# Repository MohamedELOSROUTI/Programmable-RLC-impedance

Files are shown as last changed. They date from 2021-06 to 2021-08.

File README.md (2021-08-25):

# Programmable RLC impedance

The main objective of this project is to implement a programmable RLC impedance. This circuit must cover the entire inductive-resistive-capacitive range (voltage/current phase shift between -90° and +90°). The RLC load must be able to dissipate up to 5 W. Two different implementations are suggested: the analog and digital RLC impedance. A programmable RLC impedance with adjustable R, L and C can be useful to simulate the load of a generator like a motor for example. 

## Analog impedance

The first step is to design an analog impedance. A gyrator is used in order to simulate an non ideal inductor with parallel redundant resistor. The main property of the gyrator is to invert the current-voltage characteristic of an electrical component. This way, a capacitor can be used to get a non-ideal variable inductor. The inductance can be adjusted with simple potentiometers. The second step consists in removing the parallel resistors in order to simulate an ideal inductor and reach the 90° phase-shift. This objective can be achieved by connecting the Negative Impedance Converter (N.I.C) in parallel to the gyrator. After that, a more detailed study of the output current and output voltage across the op amps allows to highlight the main limitations of such circuit : see technical report .pdf

The gyrated capacitor and inductor can be connected in parallel with a potentiometer to simulate a programmable RLC impedance as shown here under : 

**<center>Figure 1 : Kicad schematics</center>**


**<center>Figure 2 : Kicad PCB footprint </center>**



As can be seen from Figure 2, three potentiometers are placed at the top of the PCB to adjust the resistive impedance (R_var), and the inductive impedance (R5_indu and R2_indu). On the other hand, R4_capa is a potentiometer used to adjust the capacitive impedance.

The size of the printed circuit track related to the generator and the opamp power supply is chosen larger to decrease as much as possible the voltage drop (and parasitic resistance).

The red track and the green track correspond respectively to the top layer bottom layer of the PCB.

The four power opamps are placed along the same row to make easy the connection of a radiator in case of high power dissipation.

More details about the choice of the components are explained in the following article (or see ): 

https://www.researchgate.net/publication/342452048_Simulation_of_a_programmable_RLC_impedance_Analog_and_digital_implementation

**<center>Figure 3 : 3D Kicad PCB top layer </center>**


**<center>Figure 4 : 3D Kicad PCB bottom layer </center>**



**<center>Figure 5 : 3D Kicad PCB oblique view </center>**



# List of components used

1. Opamps : https://www.mouser.be/ProductDetail/Texas-Instruments/OPA548T?qs=wgAEGBTxy7kyuDG8paPgyg%3D%3D
2. Potentiometers : 
    - Adjustable Gyrated capacitor : https://www.mouser.be/ProductDetail/Bourns/PTV09A-4015U-B503?qs=pxDZlBjcsChjgaXxrSM7Lg==
    - Adjustable Gyrated inductor : https://www.mouser.be/ProductDetail/Bourns/93R1A-R22-A12L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
    - Adjustable Resistor : https://www.mouser.be/ProductDetail/Bourns/96R1A-R16-A15L?qs=iuQ%252BhjgTeig0Okk2%252Boma3A==
3. Switches : https://www.mouser.be/ProductDetail/CK/FP12SPC1B1TP00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
## Digital impedance

The second step consists in designing a digital RLC impedance. By contrast to the analog impedance, the filtering process is done digitally using a microcontroller. A software feedback control approach is employed to adjust the current amplitude and the power factor regarding the input voltage.

The objective is to maintain the impedance value constant regardless of the variation of the source voltage amplitude. Many paramaters such as the sampling frequency and the resolution of the ADC/DAC may affect the quality of the output current. The voltage can be converted to current using the Howland current source. Several simulations have been performed to visualise the performance of the digital RLC filter. See technical report .pdf.

However, another circuit made of only one opamp with negative feedback called transconductance amplifier can be used to convert the input voltage into current and inject it in the generator. It acts like a current source. The transconductance ratio is fixed by the value of the resistor R1. The Current I = Vin/R. The transconductance amplifier will be used here thanks to its simplicity (only makes use of one resistor to fix the output current). For more details, get a look at : 
 https://www.allaboutcircuits.com/textbook/semiconductors/chpt-8/voltage-to-current-signal-conversion/

**<center>Figure 1 : Transconductance amplifier simplified</center>**


Choosing R = 1 Ohm insures that Vin is a "perfect" image of the output current delivered by the generator. Let's assume that we want to simulate a 1 mF capacitor (C = 1 mF). The amplitude of the output current I should be equal to : I = Vgenerator.w.C (w=2*pi*f). Thus, the microcontroller should be able to measure at each time step the sample Vgenerator (through a ADC) and cpmpute Vin = I to simulate a constant 1 mF capacitor. A digital RLC filter must be implemented in the microcontroller. Thus a DAC is necessary to convert the digital voltage to analog voltage through the positive input of the transconductance unity gain amplifier.

More details about the implementation of the digital RLC filter can be found in technical report.pdf. The choice of the sampling frequency is crucial if one desires to maintain a phase-shift of +/- 90 degrees between input voltage and output current for ideal components (inductor/capacitor). The Z-transform allows to highlight the behaviour of the phase and magnitude depending on the sampling frequency.

Warning : One of the pins of the generator mustn't be connected to GND. Otherwise, the output if the transconductance opamp can be shorted. However, the howland current source allows to deal with grounded generators.

A special care has to be taken regarding the input voltage. A unity gain instrumentation amplifier with its high input impedance is used in order to "capture" Vgenerator at the output. The INA103 is used for this purpose. Before, connecting the output of the INA103 (Vgenerator) to input pin of the 12 bits ADC, we have to make sure that it is between 0 and 5 V. To reach the objective, a voltage divider made up with 2 equal resistors are used (5,11k Ohms). It is supplied between Vgenerator and V++ (positive supply voltage of the opamp). This will add (Vgenerator + V++)/2 to Vgenerator and make sure that the input is positive. Another voltage divider (1/4) allows to rescale Vgenerator between 0 and 5 V and feed it into the ADC. 

**<center>Figure 2 : Digital RLC impedance global overview</center>**

Important note regarding the 1 Ohm resistor that fixes the transconductance ratio : since the OPA548 output is internally buffered (can reach 5A peak), the resistor shall be able to dissipate up to 25 W. Thus the choice of the resistor is important here. Furthermore, the tolerance value shall also be low in order to keep the ratio as close as possible to 1. 

The LTO100 (F1R000FTE3) thick film power resistor can be a good candidate with its 1% tolerance.



**<center>Figure 3 : Kicad Schematics </center>**
Here's the Kicad schematics with the components used for building the digital programmable RLC impedance:



**<center>Figure 4 : Kicad PCB footprint</center>**

Here is the PCB footprint of the digital RLC impedance. The red/green circuit track corresponds respectively to the top/bottom side of the PCB. A special care has been taken to deal with high current (5 A). Thicker circuit tracks have been chosen to supply the op amps. Since the 1 Ohm resistor can afford 5 Amps, it's also important to make sure that the copper circuit track doesn't add parasitic resistance (and thus dissipation of power).

2x4 pins headers have been added to connect both the ADC and the DAC to the microcontroller. The serial communication protocole used is the I2C using SDA/SCL signals. 



**<center>Figure 5 : 3D Kicad PCB top layer </center>**
Only footprints            |  With components
:-------------------------:|:-------------------------:
|

**<center>Figure 6 : 3D Kicad PCB bottom layer </center>**
Only footprints             |  With components
:-------------------------:|:-------------------------:
 |

**<center>Figure 7 : 3D Kicad PCB oblique view </center>**



# List of components used

1. Opamp OPA 548: https://www.mouser.be/ProductDetail/Texas-Instruments/OPA548T?qs=wgAEGBTxy7kyuDG8paPgyg%3D%3D
3. Data converters : 
    - DAC : https://www.ti.com/product/DAC60502#design-development##cad-cae-symbols
    - ADC : https://www.ti.com/lit/ds/symlink/adc121c021.pdf?ts=1626049868732
3. Power resistoir : https://www.mouser.be/ProductDetail/Vishay-Sfernice/LTO100F1R000FTE3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
4. Voltage regulator : https://www.mouser.be/ProductDetail/Texas-Instruments/TPS7B8450QDCYRQ1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
5. Instrumentation op amp INA103 : https://www.ti.com/product/INA103#design-development

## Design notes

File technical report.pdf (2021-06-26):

https://lib.uliege.be | https://matheo.uliege.be

## Master's Thesis : Simulation of a programmable RLC impedance (analog and digital implementation)

### Auteur : El Osrouti, Mohamed Promoteur(s) : Redouté, Jean-Michel Faculté : Faculté des Sciences appliquées

Diplôme : Master : ingénieur civil électricien, à finalité spécialisée en "signal processing and

### intelligent robotics" Année académique : 2019-2020 URI/URL : http://hdl.handle.net/2268.2/8975

Avertissement à l'attention des usagers :

Tous les documents placés en accès ouvert sur le site le site MatheO sont protégés par le droit d'auteur. Conformément aux principes énoncés par la "Budapest Open Access Initiative"(BOAI, 2002), l'utilisateur du site peut lire, télécharger, copier, transmettre, imprimer, chercher ou faire un lien vers le texte intégral de ces documents, les disséquer pour les indexer, s'en servir de données pour un logiciel, ou s'en servir à toute autre fin légale (ou prévue par la réglementation relative au droit d'auteur). Toute utilisation du document à des fins commerciales est strictement interdite.

Par ailleurs, l'utilisateur s'engage à respecter les droits moraux de l'auteur, principalement le droit à l'intégrité de l'oeuvre et le droit de paternité et ce dans toute utilisation que l'utilisateur entreprend. Ainsi, à titre d'exemple, lorsqu'il reproduira un document par extrait ou dans son intégralité, l'utilisateur citera de manière complète les sources telles que mentionnées ci-dessus. Toute utilisation non explicitement autorisée ci-avant (telle que par exemple, la modification du document ou son résumé) nécessite l'autorisation préalable et expresse des auteurs ou de leurs ayants droit.

# Simulation of a programmable RLC

# impedance

## Analog and digital implementation

### Author : El Osrouti Mohamed

### Supervisor : Redouté Jean-Michel

### Insternship supervisor : Martin Nicolas

### Master Thesis in electrical engineering

### Signal processing and intelligent robotics

## Faculty of applied science

Graduation work carried out as a part of the Master of applied science in electrical

engineering and signal processing in order to get the grade : "Civil engineer in electrical

engineering". This thesis was suggested by the Centre spatial de Liège (CSL).

i

# Acknowledgements

I would like to express my special thanks to Prof. J.-M. Redouté and Mr N. Martin for

giving me the opportunity to work on this thesis and for all their advices. I would also

want to express my gratitude to all the staff of the space center of Liège (CSL) for all

the knowledge and experience they brought me. Thanks again to everyone who, directly

or indirectly, contributed to this master thesis. My thoughts also go to my beloved sisters,

and friends who always support me during all the progress of this work. I would especially

like to express my gratitude filled with love to my mother for her support during the

years, and to my late father who mostly contributed to my success. I love you dad.

Je tiens à remercier tout particulièrement le Prof. J.-M. Redouté et Mr Martin pour

m’avoir donné l’opportunité de travailler sur cette thèse et pour tous leurs conseils. Je

voudrais également exprimer ma gratitude à tout le personnel du centre spatial de Liège

(CSL) pour toutes les connaissances et l’expérience qu’ils m’ont apportées. Merci encore

à tous ceux qui, directement ou indirectement, ont contribué à cette thèse de maîtrise

finale. Mes pensées vont également à mes soeurs et mes amis qui me soutiennent

toujours tout au long de l’avancement de ce travail. Je voudrais surtout exprimer ma

gratitude pleine d’amour à ma mère pour son soutien au fil des années, et à mon défunt

père qui a surtout contribué à ma réussite. Je t’aime papa.

ii

# Abstract

Different kinds of electronic load simulators for testing of power supply have been

developed and commercialised. A programmable RLC impedance with adjustable R,

L and C can be useful to simulate the load of a generator like a motor for example.

Some companies may be interested in testing their voltage/current generators under

some conditions and study their behaviours. Both inductive and capacitive loads can be

simulated by adjusting the phase difference between the voltage and current waveforms.

However, there exist many drawbacks, for example, it can provide only 4 modes including

constant resistance (pure resistive load), constant power, constant current and constant

voltage to simulate simple dc load. But more often, they cannot simulate a RL or RC

load with a good dynamic response. The main objective of this master thesis is to design,

manufacture and test a programmable RLC impedance. This circuit must cover the

entire inductive-resistive-capacitive range (voltage/current phase shift between−90° and

90°). The RLC load must be able to dissipate up to 5 W. Two different implementations

are suggested : the analog and digital RLC impedance with their pros and cons.

The first step is to design an analog impedance. A gyrator is used in order to simulate

an non ideal inductor with parallel redundant resistor. The main property of the gyrator

is to invert the current-voltage characteristic of an electrical component. This way, a

capacitor can be used to get a non ideal variable inductor. The inductance can be

adjusted with simple potentiometers. The second step consists in removing the parallel

resistors in order to simulate an ideal inductor and reach the 90° phase-shift. This

objective can be achieved by connecting the Negative Impedance Converter (N.I.C) in

parallel to the gyrator. After that, a more detailed study of the output current and

output voltage across the op amps allows to highlight the main limitations of such

circuits. The voltage and current saturation of the op amps limit the available range

of inductance/capacitance values. Several simulations with a real precision op amp

(AD744) are performed. Finally, those circuits have been implemented on a breadboard

in the CSL laboratory¹ with commercial op amps such as the famous LM324. The

1For more information about the CSL, see Appendix C.

iii

results in terms of output current are compared with the simulations.

The second step consists in designing a digital RLC impedance. By contrast to the

analog impedance, the filtering process is done digitally using the microcontroller

ATMEGA2560. A software feedback control approach is employed to adjust the current

amplitude and the power factor. The objective is to maintain the impedance value

constant regardless of the variation of the source voltage amplitude. Many paramaters

such as the sampling frequency and the resolution of the ADC/DAC may affect the

quality of the output current. The voltage is converted to current using a Howland

current source. Several simulations have been performed to visualise the performance of

the digital RLC filter.

Finally, the analog and digital programmable RLC impedances are compared in terms

of their maximum input voltage, inductance/capacitance range, frequency, ... It will

be shown that the digital implementation offers more flexibility to the range of the

inductance/capacitance values than the analog impedance.

Unversity of Liège

Liège, June 2020

iv | Contents

# Contents

1 Introduction | 1
2 Analog Implementation | 6
2.5 Practical implementation of the analog RLC impedance in the CSL lab . | 54

Contents | v
3 Digital implementation | 68
4 Discussion | 85
5 Conclusion | 90
6 Appendix | 91
References | 96

vi | List of Figures

# List of Figures

2.1 Circuit that represents a non-ideal equivalent capacitor which can be

2.4 Non ideal capacitor circuit from which a cut is performed at the input. . 11 2.5 Circuit that simulates an "ideal" capacitor using a N.I.C connected in parallel 12 2.6 Output current (Is2

) of the second op amp with respect to frequency (f)

2.7 Output voltage (Vs2

) of the second op amp with respect to frequency (f)

2.9 Circuit that simulates an ideal inductor by connecting in parallel a N.I.C 22 2.10 Output current (Is2

) of the second op amp with respect to frequency (f)

2.11 Output voltage (Vs2

) of the second op amp with respect to frequency (f)

2.13 Spice simulation : current Ie and voltage Ve for a 20 nF equivalent capacitor

2.15 Behaviour of the current Ie when a real 20 nF capacitor is connected to an

2.17 Spice simulation : current Ie and voltage Ve for a 4 uF equivalent capacitor

2.18 Real 4 uF capacitor connected in parallel with an ideal AC source Ve. . . 33 2.19 Behaviour of the current Ie when a real 4 uF capacitor is connected to an

2.21 Spice simulation : current and voltage Ie and Ve for a 25 mH equivalent

2.22 Real 25 mH inductor connected in parallel with an ideal AC source Ve. . 35 2.23 Behaviour of the current Ie when a real 25 mH inductor is connected to

2.25 Spice simulation : current Ie and voltage Ve for a 250 mH equivalent

2.26 Real 250 mH inductor connected in parallel with an ideal AC source Ve. . 37 2.27 Behaviour of the current Ie when a real 250 mH inductor is connected to

2.29 Spice simulation : current Ie and voltage Ve for a 20 nF equivalent capacitor
Ce. The input voltage is a sinus of amplitude 5V and of frequency 1000 Hz. 40

List of Figures | vii

2.31 Spice simulation : current Ie and voltage Ve for a real 20 nF capacitor Ce.
The input voltage is a sinus of amplitude 5V and of frequency 1000 Hz. . | 41
2.32 Circuit that simulates a 2 nF equivalent capacitor using AD744 op amps. | 41
2.33 Spice simulation : current Ie and voltage Ve for a 2 nF equivalent capacitor
Ce. The input voltage is a sinus of frequency 1000 Hz. The op amp is the

2.35 Spice simulation : current Ie and voltage Ve for a real 2 nF capacitor Ce.
The input voltage is a sinus of amplitude 5V and of frequency 1000 Hz. . 43

2.37 Spice simulation : current Ie and voltage Ve for a real 1 Henry inductor Le.
The input voltage is a sinus of amplitude 5V and of frequency 1000 Hz. . 45

2.39 Spice simulation : current Ie and voltage Ve for an ideal 1 Henry capacitor
Le. The input voltage is a sinus of amplitude 5V and of frequency 1000 Hz. 46

2.41 Spice simulation : current Ie and voltage Ve for an equivalent 100 Henry inductor Le. The input voltage is a sinus of amplitude 5V and of frequency

2.43 Spice simulation : current Ie and voltage Ve for an ideal 100 Henry capacitor Le. The input voltage is a sinus of amplitude 5V and of frequency

2.44 RLC impedance simulated using the ad744 op amps. The amplitude of the sinus input voltage Ve is set to 5V and the corresponding frequency is

2.45 Spice simulation : current Ie and voltage Ve for Le = 1 H, Ce = 2 nF and R = 50 kΩ. The input voltage is a sinus of amplitude 5V and of frequency

2.47 Spice simulation : current Ie and voltage Ve for L = 2 H, C = 2 nF and R = 1 kΩ. The input voltage is a sinus of amplitude 5V and of frequency

2.48 Ideal switching RL-RC impedance. The user is free to choose the phase between [-90°, 0°] by activating the RC load or between [0°, 90°] by

2.50 Capacitor simulated : 2 nF. These plots compare the characteristics of the hardware implementation (on the left-hand side) and the spice simulation (on the right-hand-side) in terms of the output voltage (Vs1

) of the first
op amp, the output voltage (Vs2
) of the second op amp and the output
2.51 FFT of the output current (Ie) from the hardware implementation. . . . | 57
2.52 Capacitor simulated : 20 nF at 1000 Hz. | These plots compare the
characteristics of the hardware implementation (on the left hand side) and
the spice simulation (on the right-hand side) in terms of the output voltage
(Vs1

) of the first op amp, the output voltage (Vs2
) of the second op amp

viii | List of Figures
2.53 FFT of the output current (Ie) from the hardware implementation. . . . | 59
2.54 Frequency response of the equivalent capacitor circuit (with LM324 op amps) for different capacitor values : 2 nF (left figure), 20 nF ( right
figure). Small signal analysis with amplitude 1 Volt | | 59
2.55 Circuit that simulates an ideal inductor using the LM324 op amp | | 60
2.56 Inductor simulated : 100 mH. These plots compare the characteristics
of the hardware implementation (on the left hand side) and the spice simulation (on the right-hand side) in terms of the output voltage (Vs1

)
of the first op amp, the output voltage (Vs2
) of the second op amp and the
output current of the source generator (Ie) | | 62
2.57 FFT of the output current (Ie) from the hardware implementation. . . . | 63
2.58 Inductor simulated : 1 H. These plots compare the characteristics of the hardware implementation (on the left hand side) and the spice simulation
(on the right-hand side) in terms of the output voltage (Vs1

) of the first
op amp, the output voltage (Vs2
) of the second op amp and the output
current of the source generator (Ie) | | 64
2.59 FFT of the output current (Ie) from the hardware implementation. . . . | 65
2.60 Frequency response of the gyrator circuit (with LM324 op amps) for different inductor values : 10 mH (top left figure), 100 mH (top right
figure) and 1 H (last figure). Small signal analysis with amplitude 1 Volt. | 66
3.1 Schematic of the digital implementation of the RLC impedance | | 68
3.2 Simplified representation of the digital implementation. | The current
injected to the generator is controlled by the microcontroller. | It’s
proportional to the current that would flow into an inductor or capacitor. | 70
3.3 Simulated capacitor : 1 mF. Left plot : continuous output current. Right plot : discrete output current generated by the microcontroller at sampling
frequency 5000 Hz. The input voltage is a 100 Hz sine wave | 72
3.4 Simulated inductor : 1 mH. Left plot : continuous output current. Right plot : discrete output current generated by the microcontroller at sampling
frequency 5000 Hz. The input voltage is a 100 Hz sine wave | | 72
3.5 Bode plot of a continuous ideal capacitor (1 mF) | | 74
3.6 Bode plot of a continuous ideal inductor (1 mH) | | 75
3.7 Bode plot of the digital ideal capacitor (1 mF) transfer function for different sampling frequency : F s1, F s2,F s3, F s4 and F s5 respectively equal to 1,
2, 3, 4 and 5 kHz | 77
3.8 Bode plot of the digital ideal inductor (1mH) transfer function for different sampling frequency : F s1, F s2,F s3, F s4 and F s5 respectively equal to 1,
2, 3, 4 and 5 kHz. | | | 78
3.9 Full-wave precision rectifier | | 80
3.10 Comparator that outputs logical "1" if the input voltage is below the
reference : 0 V | | 80
3.11 Voltage follower | | 81
3.12 Howland current source. Vdac is the controlled voltage at the output of
the DAC. It has to be converted into current. Vin_micro is the voltage of
the generator which goes into the input pin of the microcontroller (before
the voltage rectifier) | 82
3.13 Final embedded digital implementation. See Appendix A for a landscape
format of the digital implementation. | | | 85

List of Figures | ix
6.1 Final digital implementation of the programmable RLC impedance. . . . | 91
6.2 Final analog implementation of the programmable RLC impedance. . . . | 92

x | List of Tables

# List of Tables

4.2 Comparisons of available inductance/capacitance ranges between

1

# 1 Introduction

## 1.1 Motivation and State of art

Simulated loads are crucial if an industry desires to test its power equipment under some

specific conditions (fixed inductance range, ...). Those features should provide real world

simulation capabilities and prevent overstressing the instrument. Furthermore, a DC/AC

electronic impedance plays an essential role in current and future power source testing,

especially in the field of renewable energies. Different kinds of loads maybe relevant

according to the technical specifications :

1. constant power load : the load adjusts its internal impedance to dissipate constant

power.

2. constant impedance : two kinds : a resistive impedance and a z impedance which

covers the entire complex plane.

A well-known programmable active impedance has been studied and developed by

Guan-Chyun Hsieh and Jung-Chien Li[1] in 1993. They suggested an AC active load

simulator circuit which can simulate a desired load impedance with a power factor

from zero to unity. They employed a software feedback control approach to adjust the

current amplitude and the power factor for the purpose of maintaining the impedance

value constant regardless of the variation of the source voltage amplitude. The Ph.D

of Wei Feng[2] proposes a proper schematic of the inductive/capacitive electronic loads

based on the H-bridge dc-dc converter. Another relevant research paper [3] presents

a programmable power electronic, constant power load (CPL) using a dc/dc step-up

(boost) converter.

Many programmable kinds of impedances have been developed. The LED Load Simulator

Model 63110A sold by Chroma[4] can simulate the behaviours of LED’s. It contains a

programmable interface to model the LED’s dynamic resistance. Unfortunately, it’s not

able to simulate an inductive or capacitive load. Recently, Measurements International

developed a programmable impedance simulator which covers the entire complex plane[5].

2 | 1.2 Analog Impedance

This feature has been designed to address and fill the need requirement for a better way

to calibrate LCR meters. The Z100 model covers the full calibration of LCR meters

over simulated impedance from 100 Hz to 20 kHz. The magnitude of the synthesised

impedances ranges from 1 Ω to 10 MΩ with an arbitrary phase angle. In the Z1000,

the current and the voltage measured by the LCR meter to calculate the impedance are

independently generated by two external voltage sources. Adjusting the amplitudes and

the relative phase of the voltage sources, the synthesized impedance can cover the entire

complex plane. The developers do not reveal more information about the hardware of

their product. They only mention that their device is based on a feedback loop in order

to control the output current and the phase. One thing is certain, the device is only able

to dissipate miliwatts of power and can’t be used to simulate the load of a generator.

## 1.2 Analog Impedance

The first objective is to simulate an analog RLC impedance circuit where the value

of the resistor, the capacitor and the inductor are freely chosen by a random user.

There are useful circuits for designing a filter or simulating a motor, for example. The

user wouldn’t have to change physically the inductor component in order to change

its value. The same would apply for the capacitor even though digitally controlled

variable capacitors are available. For example the NCD2400M[6] component is a digital

programmable capacitor which acts like a capacitance decade box. Many capacitors are

connected in parallel and some switches are open or closed in order to activate or not

the capacitors. Such components won’t be used for the rest of the project due to their

large step size (coupled to a small available capacitance range).

The phase between the voltage and current should be between [-90°, 90°]. -90° corresponds

to a pure capacitor and 90° corresponds to pure inductor. The presence of the resistor

changes the phase between -90° and 90°. Adjusting the value of the resistor is easy, a

simple analog potentiometer can be used. Furthermore, some digital potentiometers are

available and can be controlled via a microcontroller. For the capacitor and the inductor,

it’s a little bit more complicated. Useful circuits, named gyrators[7], made of operational

amplifiers can be used in order to simulate the value of the capacitor or inductor by

1.2 Analog Impedance | 3

adjusting potentiometers[8].

As a first approximation, the op amps are assumed to be ideal:

1. Infinite open-loop gain which doesn’t depend on frequency.
2. Infinite input impedance which implies zero input current.
3. Zero input offset voltage.
4. Infinite output voltage range.
5. No output current limitation (this condition limits the range of inductor and

capacitor values).

6. Zero output impedance (sometimes not specified in datasheets).
7. Infinite bandwidth with zero-phase shift and infinite slew rate.
8. Zero noise.
9. Infinite common-mode rejection ratio (CMRR).

The circuit that has to be simulated is shown in Fig1.1. It represents a resistor, a capacitor

and an inductor connected in parallel whose values can variate. An equivalent RLC series

circuit can be derived from this.

4 | 1.3 Digital Impedance

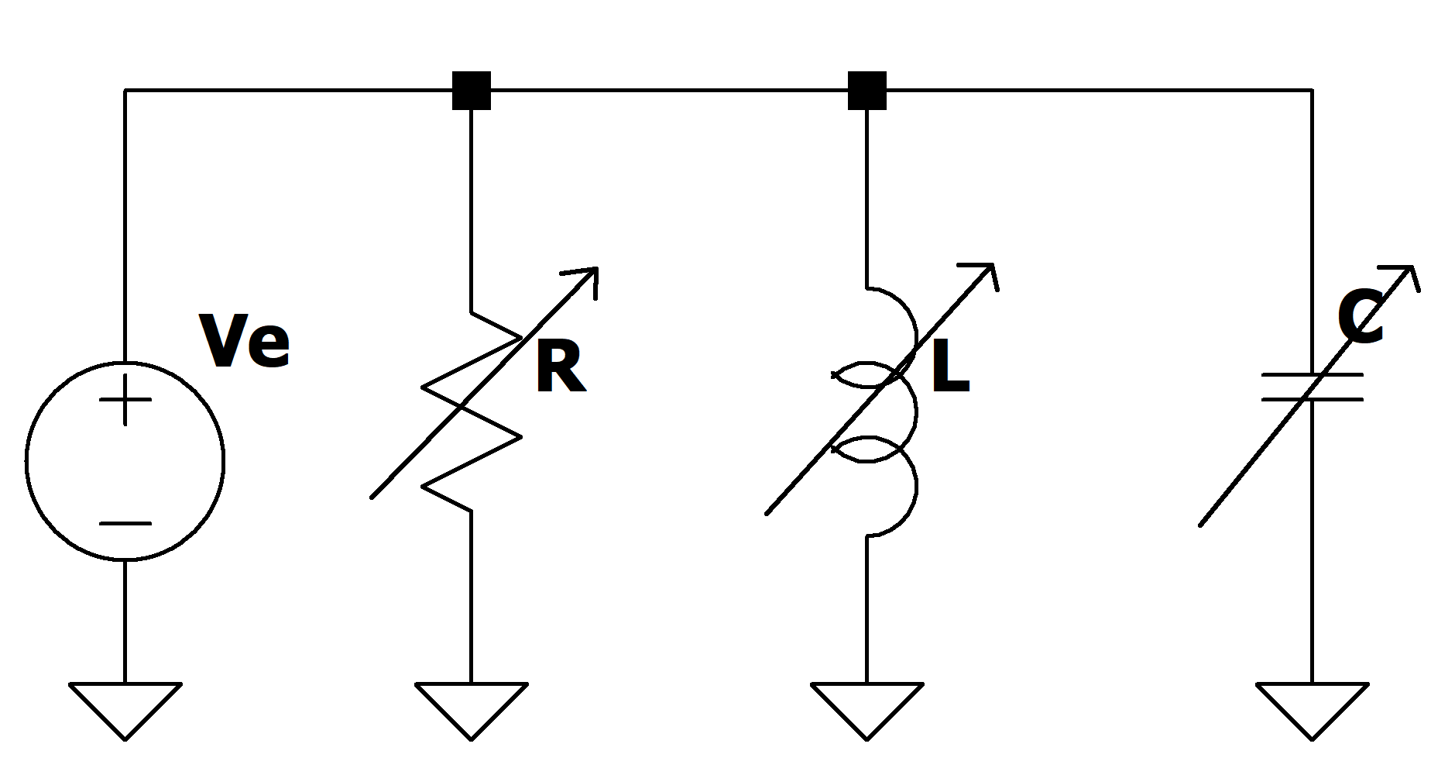
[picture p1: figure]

Figure 1.1: RLC parallel impedance

## 1.3 Digital Impedance

By contrast to the analog impedance, the filtering process is performed digitally. The

value of the capacitor and the inductor are adjusted on software. The microcontroller is

in charge of computing the output current of the generator. Many parameters may affect

the quality of the digital impedance such as

- the sampling frequency (limited by the internal clock of the microcontroller),
- the resolution of the ADC (determined by the number of bits),
- the resolution of the DAC,
- the maximum input voltage of the µC,

The digital implementation can be modelled using a voltage-controlled current source

where the microcontroller is in charge of:

1. Measuring the input voltage thanks to its ADC
2. Computing the output current that should be injected to the generator depending

on R, L, C and type of connectivity (parallel or series).

3. Outputting the voltage (image of the output current) to the DAC. This one will be

thus converted to current thanks to voltage controlled current source.

1.3 Digital Impedance | 5

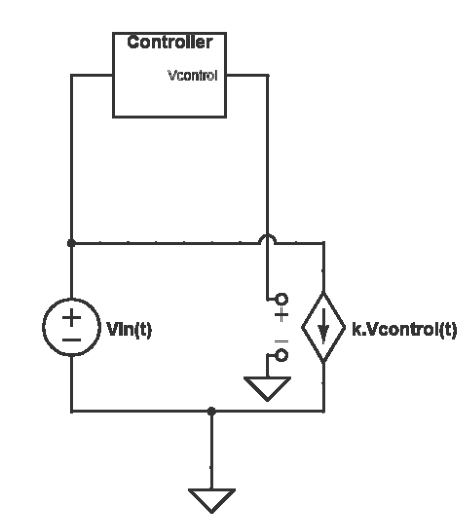
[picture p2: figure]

Figure 1.2: Simplified representation of the digital implementation.

The current injected to the generator is controlled by the microcontroller. It’s

proportional to the current that would flow into an inductor or capacitor.

6

# 2 Analog Implementation

## 2.1 Simulating a variable capacitor with op amps

### 2.1.1 Non-ideal variable capacitor

Figure 2.1: Circuit that represents a non-ideal equivalent capacitor which can be adjusted thanks to R5, R4 and C.

This circuit is useful in order to simulate an equivalent capacitor Ce from another

capacitor C. Let Yˆ be the admittance of the capacitor :

Yˆ = jwC

. The equivalent admittance of this circuit can be written as

Yˆ
e =

ˆIe
Vˆ
e

2.1 Simulating a variable capacitor with op amps | 7

### 2.1.2 Analysis

Assuming an ideal op amp : V

+ = V

− = 0V

I

+ = I

− = 0 → ˆIC = ˆIR4
. The following equations can be easily derived using ohm law

across resistors and capacitors :

ˆIR4 = −

Vˆ
s
R4

= Yˆ Vˆ
e | (i)

ˆIR5 =

Vˆ

e − Vˆ
s
R5

(ii)

Injecting (i)→ (ii) :

ˆIR5 = ˆIR4
(

1
Y Rˆ
5

+

R4
R5
) | (iii)

Thus:

ˆIR5 + ˆIR4 = ˆIR4
(

1
Y Rˆ
5

+

R4 + R5
R5
) = ˆIe | (iv)

This way, the input admittance of this circuit is expressed as : Yˆ
e =

1
R5

+Yˆ (1 + R4
R5

). This

circuit thus simulates a non ideal capacitor with a resistor R5 connected in parallel. The

expression of the equivalent capacitor is : Ce = C(1 + R4
R5

). The value of the capacitor Ce

can be adjusted thanks to a potentiometer R4 if the resistor R5 is fixed. R5 should be

chosen sufficiently high in order to decrease as much as possible the value of the parallel

resistor and get closer to an "ideal" capacitor. It also limits the output current of the op

amp. The dissipation factor( or tan(ϕ) of the non ideal equivalent capacitor is:

tan(ϕ) = | 1 wC(R4 + R5)

### 2.1.3 Design of components

As said previously, choosing a large impedance for R5 allows us to neglect the

parallel resistor at high frequency and decrease the output current drawn by the AO.

Unfortunately, it decreases the range of available capacitance values.

8 | 2.1 Simulating a variable capacitor with op amps

Figure 2.2: Equivalent circuit derived from Fig 2.1

An intuitive approach is adopted here in order to choose the "optimal" values for the

resistors and the capacitor. In order to limit as much as possible the output current of

the AO ( ˆIs), the following condition should always be satisfied :

ˆIs|max = |Vˆ

e(Yˆ +

1 + R4Yˆ

R5

)|max < ILim

Where ILim is the maximum output current that can be drawn by the AO. R5 is chosen

high (100 kΩ) in order to minimise the dissipation factor. Assuming |Vˆ
e|max = 5V :

|Yˆ +

1 + R4Yˆ

R5

|max < 25−1
(Siemens)

such as the maximum output current can not exceed :

|Vˆ
e|max(Volt)
25(Ohm)

= 200mA

2.2 Ideal variable capacitor | 9

It can be shown that the frequency should be less than a certain value depending on R4

and C :

f < 25−1R5 − 1

R5 + R4

1
2πC (Hz)

Assuming that R4 takes values between [10, 100 kΩ], the fundamental frequency of the

input voltage should be less than

f < 25−1R5 − 1

R5 + R4max

1
2πC (Hz)

f < 3, 18 × 10−3

C

(Hz)

The capacitance value fixes the admissible frequency range.

If Coming back to the expression of the equivalent capacitor :

Ce = C(1 + R4
R5

)

Ce can only take values between [C, 2C] with respect to R4 (∈ [10, 100kΩ]). Choosing a

high value of R5 unfortunately limits the range of the capacitance.

In the following section it will be studied how this parallel resistor can be removed by

connecting in parallel a well-known circuit called : Negative Impedance Converter

(NIC).

## 2.2 Ideal variable capacitor

The best way to remove the parallel resistor to the equivalent capacitor is to connect

in parallel a negative impedance to the previous circuit[9]. The absolute value of the

impedance negative has to be equal to R5 in order to cancel its effect. The physics

behind a negative impedance is to inject the current drawn by resistor R5 to the equivalent

capacitor from negative impedance −R5.

10 | 2.2 Ideal variable capacitor

### 2.2.1 Negative Impedance Converter (N.I.C)

The concept of the N.I.C is introduced using the following circuit:

Figure 2.3: Negative Impedance Converter (N.I.C)

The equivalent impedance of this circuit is :

Zˆ
e =

Vˆ
e
ˆIe

The following equations are derived using the Ohm law across the components :

ˆIe =

Vˆ

e − Vˆ
s
Z

(i)

Vˆ
e =

Vˆ
sR1
R1 + R2

(ii)

Injecting (ii)→ (i) :

ˆIe =

−Vˆe(R1+R2)
R1

+ Vˆ
e
Z

(iii)

2.2 Ideal variable capacitor | 11

Thus:

Zˆ
e =

−ZR1
R2

(iv)

The equivalent impedance has to be designed such that it perfectly equals the parallel

resistance R5 in absolute value.

### 2.2.2 Coupling the N.I.C to the non ideal capacitor

By performing a cut in the pin of the capacitor from fig 2.1, the following circuit is

obtained:

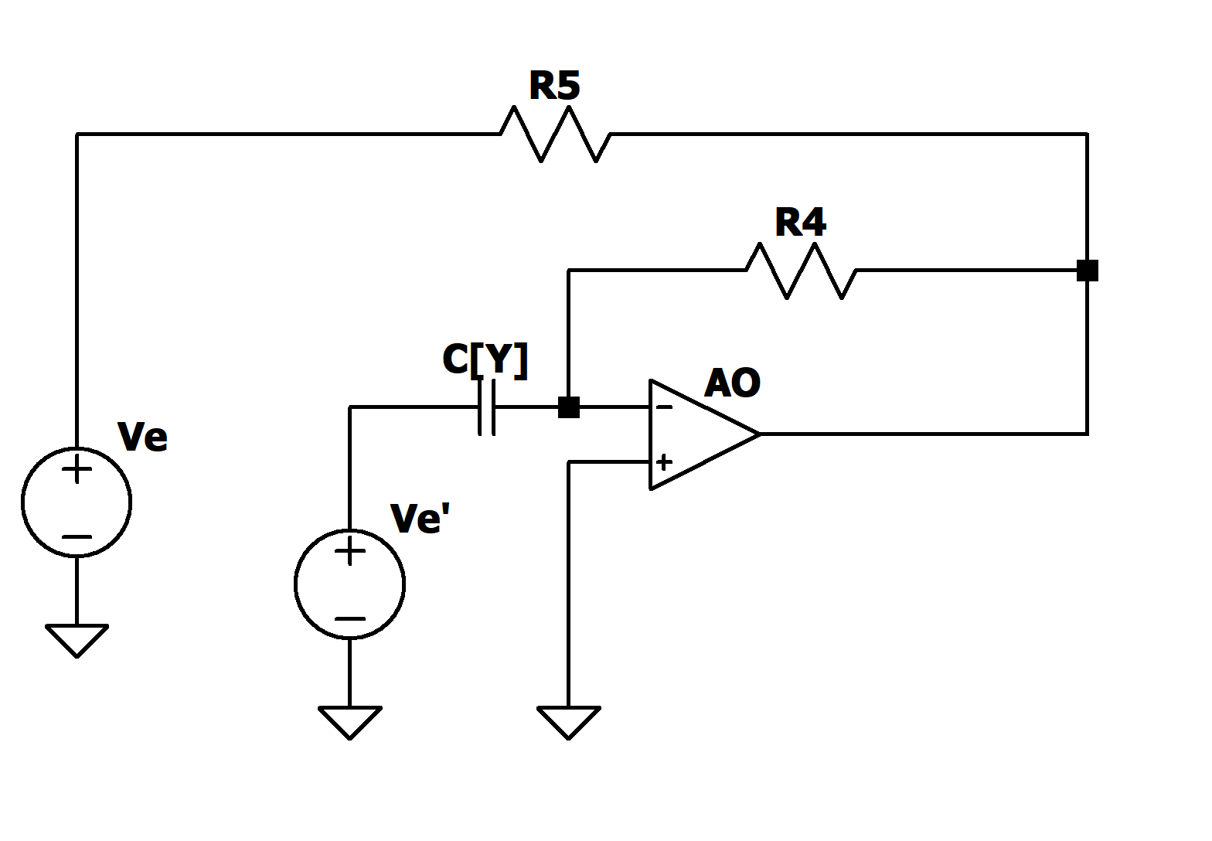
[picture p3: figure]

Figure 2.4: Non ideal capacitor circuit from which a cut is performed at the input.

As performed in sub section 2.3, the equivalent admittance can be computed. Let k be

the voltage ration between Vˆ

e and Vˆ ′
e

:

ˆIR4 = −

Vˆ
s
R4

= kYˆ Vˆ
e | (i)

12 | 2.2 Ideal variable capacitor

ˆIR5 =

Vˆ

e − Vˆ
s
R5

(ii)

Yˆ
e =

ˆIR5
Vˆ
e

=

Vˆ

e + kYˆ Vˆe
R4
R5Vˆ
e

(iii)

It results that the equivalent admittance is quite similar to the one derived from section

2.1.1 :

Yˆ
e =

1
R5

+ kYˆ

R4
R5

The parallel resistor R5 is still here, so the objective is to cancel it by connecting a N.I.C

in parallel :

Figure 2.5: Circuit that simulates an "ideal" capacitor using a N.I.C connected in parallel

### 2.2.3 Analysis

### 2.2.3.1 Equivalent admittance

The mathematical expression of the equivalent admittance of this circuit can be checked

and in which condition it represents a pure capacitor.

2.2 Ideal variable capacitor | 13

Yˆ

e = Yˆ

e1 + Yˆ
e2

(i)

Where Yˆ
e1

is the N.I.C admittance and Yˆ
e2

is the admittance of the non ideal capacitor.

Yˆ
e1 = −(

R3R1
R2

)

−1
(ii)

Yˆ
e2 =

1
R5

+ k

Y Rˆ
4
R5

(iii)

Injecting (ii) + (iii) → (i) :

Yˆ
e =

1
R5

+ k

Y Rˆ
4
R5

− (

R3R1
R2

)

−1
(iv)

Where k =

R1+R2
R1

If the following condition is always satisfied :

R5 =

R3R1
R2

(v)

Then, the redundant resistor is cancelled and the equivalent input admittance corresponds

to a pure capacitor :

Yˆ
e =

R1 + R2
R1

Y Rˆ
4
R5

(vi)

Ce =

R1 + R2
R1

R4C
R5

(vii)

If the resistances R1, R2, R3, R5 are fixed such that condition (v) is satisfied, the

equivalent capacitance Ce can be adjusted thanks to a simple potentiometer R4.

### 2.2.3.2 AC output current of op amps

Most of op amps are only able to to draw a limited output current. It is then a good idea

to express the output current of the op amps in terms of surrounding components.

14 | 2.2 Ideal variable capacitor

ˆIR3 = ˆIS1 + ˆIC + ˆIR2
(i)

ˆIR2 =

Vˆ
e
R1

(ii)

Vˆ
R2 =

R2
R1

Vˆ
e + Ve | (iii)

ˆIR3 =

Vˆ

e − Vˆ
s1
R3

(iv)

Vˆ

s1 = Vˆ

e(1 + R2
R1
) | (v)

ˆIC = Vˆ

s1 Yˆ | (vi)

Vˆ

s2 = −ˆICR4 | (vii)

ˆIR5 =

Vˆ

e − Vˆ
s2 R5 | (viii)
ˆIs2 = ˆIR5 + ˆIC | (ix)

Injecting (v) → (iv) :

ˆIR3 = −

Vˆ
eR2 R3R1 | (x)

Injecting (v) → (vi) :

ˆIC = Vˆ

e(1 + R2
R1
)Yˆ | (xi)

Injecting (ii) + (x) + (xi) → (i) the output current of the first op amp can be deduced:

ˆIs1 = −Vˆ
e(

R2
R3R1

+ (1 + R2
R1

)Yˆ +

1
R1
) | (xii)

Injecting (xi) → (vii) :

Vˆ
s2 = −Vˆ

e(1 + R2
R1

)Y Rˆ
4 | (xiii)

(xiii) → (viii) :

ˆIR5 =

Vˆ

e + Vˆ
e(1 + R2
R1

)Y Rˆ
4
R5
| (xiv)

(xi) + (xiv) → (ix) :

ˆIs2 = Vˆ
e

(
(1 + R2
R1

)Yˆ (1 + R4
R5

) + 1
R5

)
(xv)

2.2 Ideal variable capacitor | 15

### 2.2.3.3 DC output current of op amps

Since a capacitor is used in this circuit, a constant component of the op amp output

current can be superposed to the AC component. The DC component of the output

currents of the op amps will be computed. A DC analysis can be performed by assuming

a constant voltage across the capacitor (Vc) and no current (IC = 0 A).

Let v(t) be the continuous time voltage across a component, vˆ(t) is its AC component

(characterised previously by a phasor) and V be its DC component.

It can be easily shown that :

ˆIR1 = ˆIR2 =

Vc
R1 + R2

(i)

ˆIR3 =

Vc
R1 + R2

(ii)

The DC output current of the first op amp can be deduced from (i) and (ii) :

ˆIs1 = IR2 + IR3 = Vc(

1
R1 + R2

+

1
R3
) | (iii)

Now, Vc has to be computed. Let vc(t) be continuous time voltage across the capacitor,

it can be deduced thanks to the Ohm’s law that :

vc(t) = ve(t) + ve(t)

R2
R1 + R2

(iv)

Assuming that ve(t) is a pure sine wave with no DC component, then Vc = 0 V. As a

result, Is1 = 0 A.

If a DC analysis is also performed on the second op amp, it can be shown Vs2 = 0 V

because no current flows in the resistor R4 (IR4 = 0 A). Since the DC voltage across R5

is 0 V, it implies : IR5 = 0 A. So the DC component of the output current is2

(t) is 0 A

(Is2 = 0 A).

16 | 2.2 Ideal variable capacitor

### 2.2.3.4 Design of components

Short summary :

Ce =

R1 + R2
R1

R4
R5
C | (i)

Condition :

R5 =

R3R1
R2
| (ii)

The two current limitations :

ˆIs1

| = |Vˆ
e(

R2
R3R1

+ (1 + R2
R1

)Yˆ +

1
R1
)| < ILim | (iii)

ˆIs2

| = |Vˆ
e|

(
(1 + R2
R1

)Yˆ (1 + R4
R5

) + 1
R5

)
| < ILim | (iv)

The two output voltage limitations :

|Vˆ
s1

| = |Vˆ

e|(1 + R2
R1
) < Vsat | (v)

|Vˆ
s2

| = |Vˆ

e|(1 + R2
R1
)|Yˆ |R4 < Vsat | (vi)

For the sake of simplicity, R2 is chosen equal to R1. The condition (ii) then becomes R3

= R5. The third condition (iii) gives :

ˆIs1 = Vˆ
e(

R2
R3R1

+ (1 + R2
R1

)Yˆ +

1
R1

)

ˆIs1
| ≤ |Vˆ
e|(

1
R3
+ 2|Yˆ | +

1
R1

)

Making the assumption that the output current ILim can not exceed 300mA. The resistors

should always satisfy these conditions : R1 > 50Ω, R3 > 50Ω and :

|Yˆ | < 50−1

wC < 50−1

f < 1 50.2πC

2.2 Ideal variable capacitor | 17

This way, the AC input current doesn’t exceed 300 mA. From the previous expression,

it can be seen that the frequency must not exceed a certain value (depending on C) in

order to keep the output current under the limit (300 mA taken in the example). The

DC component of the output current is not taken into account for the moment.

Adopting the same philosophy for the second op amp concerning the condition (iv) :

ˆIs2 = Vˆ
e

(
(1 + R2
R1

)Yˆ (1 + R4
R5

) + 1
R5

)

ˆIs2

| ≤ Vˆ
e

(
(1 + R2
R1

)|Yˆ |(1 + R4
R5

) + 1
R5

)

Choosing 2|Yˆ |(1 + R4
R5

) + 1
R5

≤ 10−1 allows us to fix the maximum current to 500 mA. it

results that :

|Yˆ | ≤

10−1 −
1
R5
2(1 + R4
R5

)

wC ≤

10−1 −
1
R5
2(1 + R4
R5

)

f ≤

10−1 −
1
R5
2.2πC(1 + R4
R5

)

R5is chosen equal to 5000 Ω in order to let R4 free to take values between [50, 1M]. Taking

the most unfavourable case (R5 = 5000Ω and R4 = 1 MΩ), the maximum frequency

should never exceed 40 kHz.

If C = 1 nF → fmax = 40 KHz.

Since Ce = 2 R4
R5

C ∈ [20 pF, 0.4 uF]

### 2.2.3.5 Output current and output voltage

As said previously, op amps can saturate if the output voltage or the output current is

above a certain limit. So, it is interesting to plot those two quantities as a function of

the frequency and the equivalent capacitance. It will be easier to determine the available

frequency range and capacitance range in order to avoid any voltage or current saturation.

18 | 2.2 Ideal variable capacitor

As detailed in the previous section, the resistors R2 and R1 are chosen equal. R5 is fixed

to 5000 Ω and R4 is free to take values between [50 Ω, 1 MΩ].

Figure 2.6: Output current (Is2

) of the second op amp with respect to frequency (f) and equivalent capacitance (Ce).

Figure 2.7: Output voltage (Vs2

) of the second op amp with respect to frequency (f) and equivalent capacitance (Ce).

As can be seen from these above figures, for a given equivalent capacitance Ce, the output

2.2 Ideal variable capacitor | 19

voltage/current increases with frequency. This is logical since a capacitor behaves like

a short-circuit at high frequencies. The choice of the op amp should be optimal such

that the available range of capacitance values and frequency is maximised without any

saturation.

20 | 2.3 Simulating a variable inductor with op amps

## 2.3 Simulating a variable inductor with op amps

### 2.3.1 Non-ideal variable inductor

Some famous circuits called "gyrators" are able to simulate a non-ideal inductor from op

amps.

The circuit has the same architecture as fig 2.1 but the resistor and the capacitor is

inverted. It can be shown that the equivalent admittance of this circuit is :

Ye = (1 + 1
Y Rˆ
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
R4R5Yˆ

+

1
R4

+

1
R5

Then the equivalent admittance and parallel resistors can be determined :

Le = R4R5C

in parallel with R4 and R5. The equivalent inductance can be adjusted using

potentiometers R4 and R5 but the parallel resistors change too.

### 2.3.2 Ideal variable inductor

As performed with the non ideal capacitor, a N.I.C can be connected in parallel to the

non ideal inductor in order to remove the parallel resistors.

Analysis

### 2.3.2.1 Equivalent admittance

Let Yˆ
e1

, Yˆ

e2 be respectively the admittance of the N.I.C and the gyrator and Yˆ e be the

equivalent admittance of the whole circuit.

2.3 Simulating a variable inductor with op amps | 21

Figure 2.8: Equivalent RL circuit

Ye = Ye1 + Ye2

= −

R2
R1R3

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
R4R5Yˆ

If the following condition is satisfied :

R2
R1R3

=

1
R4

+

1
R5

the equivalent admittance corresponds to pure inductor :

Le = R4R5C

If the value of the capacitance is fixed, it’s possible to adjust the value of the inductance

thanks to resistors R4, R5.

Furthermore, the op amps are limited in output current. It’s thus necessary to make a

22 | 2.3 Simulating a variable inductor with op amps

Figure 2.9: Circuit that simulates an ideal inductor by connecting in parallel a N.I.C

more detailed study of the output currents.

### 2.3.2.2 AC output current of op amps

The AC component of the output current of the op amps will be derived by using phasors

for the currents and voltages. The Laplace transform is performed for the capacitor

impedance.

ˆIs1 = ˆIR2 − ˆIR3
(i)

ˆIR2 =

Vˆ
e
R1

(ii)

Vˆ

R2 = ˆIR2R2 | (iii)

Vˆ

s1 = Vˆ

e + Vˆ e

R2 R1 | (iv)

ˆIR3 = (Vˆ

e − Vˆ
s1
)/R3 | (v)

ˆIR4 = Vˆ
e/R4 | (vi)

2.3 Simulating a variable inductor with op amps | 23
ˆIs2 = ˆIR4 + ˆIR5 | (vii)

Injecting (iv) → (v) :

ˆIR3 =

(
Vˆ

e − Vˆ

e(1 + R2
R1

)

)
/R3 | (viii)

(ii) + (viii), the output current of the first op amp can be deduced:

ˆIs1 =

Vˆ
e
R1

(R2

R3

+ 1)
(ix)

ˆIR5 =

Vˆ

e − Vˆ
s2
R5

(x)

Vˆ
s2 = −

ˆIR4
Yˆ

(xi)

Injecting (xi) → (x) :

ˆIR5 = (Vˆ
e +

ˆIR4
Yˆ
)/R5 | (xii)

Injecting (vi) + (xii) → (xiii) :

ˆIR5 = Vˆ
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
Y Rˆ
5

+ 1))
(xiii)

(xiii) + (vi) → (vii), the output current of the second op amp can be deduced:

ˆIs2 = Vˆ
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
R4R5Yˆ
) | (xiv)

### 2.3.2.3 DC the output current of op amps

Now, the DC component of the output currents of the operational amplifiers will be

derived. A DC analysis can be performed by assuming a constant voltage across the

capacitor (Vc) and no current (IC = 0 A).

It results than the output current that is injected in the op amp can only be delivered

from the resistor R5 :

24 | 2.3 Simulating a variable inductor with op amps

IR5 =

Vc
R5

= Is2

(i)

Where Is2

is the DC component of the output current of the second op amp.

Let vc(t) be the voltage across the capacitor with vc(t) = Vc + ˆvc(t). Vc is the DC

component and vˆc(t) the AC component characterised by a phasor (studied in the previous

section 4.1.2).

Knowing that :

ic(t) = C

dvc
dt | (ii)

with ic(t) = iR4

(t) = ve(t)
R4

The voltage vc(t) can be obtained by a simple integration :

vc(t) = 1
CR4

∫
ve(t)dt | (iii)

−1
CR4

Ve

cos(wt)
w
+ Vc = vc(t) | (iv)

Assuming that the capacitor is initially discharged (vc(t = 0) = 0 V), it can be deduced

that

Vc =

1
CR4

Ve
w

(v)

From (i), the DC output current of the second op amp can be deduced : (v) → (i)

Is2 =

1
CR4R5

Ve
w

(vi)

Concerning the first op amp, it can be easily shown that the DC output current is equal

to 0 A.

### 2.3.2.4 Design of components

Here’s a short summary of previous results :

2.3 Simulating a variable inductor with op amps | 25
Le = R4R5C | (i)

Condition :

R3 =

R2 R1

R4R5 R4 + R5 | (ii)

The two current limitations :

ˆIs1
| =

|Vˆ
e|
R1

(R2

R3

+ 1)
< ILim | (iii)

ˆIs2

| = |Vˆ
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
R4R5Yˆ
)| < ILim | (iv)

The two output voltage limitations :

|Vˆ
s1

| = |Vˆ

e|(1 + R2
R1
) | (v)

Vˆ
s2 =

|Vˆ
e|
|Yˆ |R4

(vi)

Where ILim is the maximum output current that can be drawn by the op amp.

Choosing R2 = R3 will always lead to : |

ˆIs1

| = 2|Vˆe|
R1

(condition (iii) ). So the maximum

output current of the first op amp is only limited by resistor R1. The condition (ii) is

simplified :
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
Concerning the condition (iv), it’s a little bit more complicated :

|Is2

| ≤ |Vˆ
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
R4R5wC )

The output current |

ˆIs2
| is limited by R4, R5 and the admittance wC.

If the available resistance range of R4, R5 and the value of the capacitor are well chosen,

the condition (iv) can be satisfied for a large frequency range.

26 | 2.3 Simulating a variable inductor with op amps

If the available values of R4 and R5 and the capacitance C are well chosen, the output

current limitation (iv) can be satisfied for a large frequency range.

Taking R4, R5, R5R4wC > 50 Ω allows to make sure that the output current of the

second op amp won’t exceed 300 mA :

wC ≥

1
50

f ≥

1
50.2πC

Concerning the first op amp, the maximum output current would never exceed 400 mA.

Assuming R4 takes values between [50, 1MΩ] and R5 = 50Ω.

If C = 0.1 mF → Le ∈ [250m, +∞] with fmin = 31.8 Hz.

If C = 10 uF → Le ∈ [25m, +∞] with fmin = 318 Hz

The DC component of the output current has not been taken into account for the design

of components.

### 2.3.2.5 Output current and output voltage

As said previously, op amps can saturate if the output voltage or the output current is

above a certain limit. So, it is interesting to plot those two quantities as a function of

the frequency and the equivalent inductance. It will be easier to determine the available

frequency range and capacitance range in order to avoid any voltage or current saturation.

R5 is fixed to 1000 Ω and R4 is free to take values between [50 Ω, 100 kΩ].

2.3 Simulating a variable inductor with op amps | 27

Figure 2.10: Output current (Is2

) of the second op amp with respect to frequency (f) and equivalent inductance (Ce).

Figure 2.11: Output voltage (Vs2

) of the second op amp with respect to frequency (f) and equivalent inductance (Ce).

As can be seen from these above figures, for a given frequency, the output voltage/current

is inversely proportional to the inductance. The choice of the op amp should be optimal

such that the available range of inductance values and frequency is maximised without

28 | 2.3 Simulating a variable inductor with op amps

any saturation.

2.4 Spice simulation | 29

## 2.4 Spice simulation

### 2.4.1 Ideal op amps

The following simulations are performed assuming ideal operational amplifiers. The

resistors around the op amps and the available range of frequencies are designed such

that the output current of the op amps doesn’t exceed hundreds of mA’s. The software

LtSpice[10] is used for simulations.

### 2.4.1.1 Ideal capacitor simulation

The resistors R5, R3 are fixed to 50 Ω in order to let the potentiometer R4 variate in a

large range. The resistors R2 and R1 are made equal to 100 kΩ. This way, the N.I.C

removes the parallel redundant resistor R5 as detailed in section 2.

The only parameter that is used to adjust the capacitor is the potentiometer R4. Let’s

simulate two random capacitor values : 20 nF and 4 uF. The following formula is used :

Ce = 2

R4
R5

C

For the following examples, C is chosen equal to 1 nF.

Let’s compare these results with a real capacitor connected in parallel with voltage source

Ve :

It can clearly be seen that the circuit made of op amps simulates with high accuracy the

20 nF capacitor. Let’s change the order of magnitude of the equivalent capacitor to 4 uF

by selecting R4 = 100 kΩ.

Lets compare these results with a real 4 uF capacitor connected in parallel with a sine

voltage source Ve. The simulated circuit made of op amps replicates exactly the same

behaviour as for an ideal 4 uF capacitor. The N.I.C plays a crucial role for simulating an

ideal equivalent capacitor depending on the value of the potentiometer R4 : Ce = f(R4).

It can be noticed that the phase shift between the current source and the voltage source

is -90 degrees.

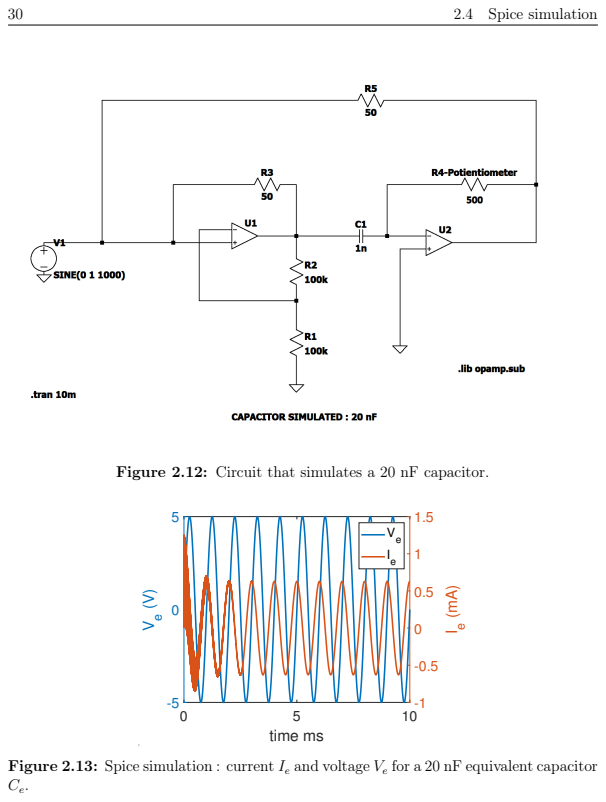
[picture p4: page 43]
2.4 Spice simulation; time ms

Figure 2.12: Circuit that simulates a 20 nF capacitor.

Figure 2.13: Spice simulation : current Ie and voltage Ve for a 20 nF equivalent capacitor

2.4 Spice simulation | 31

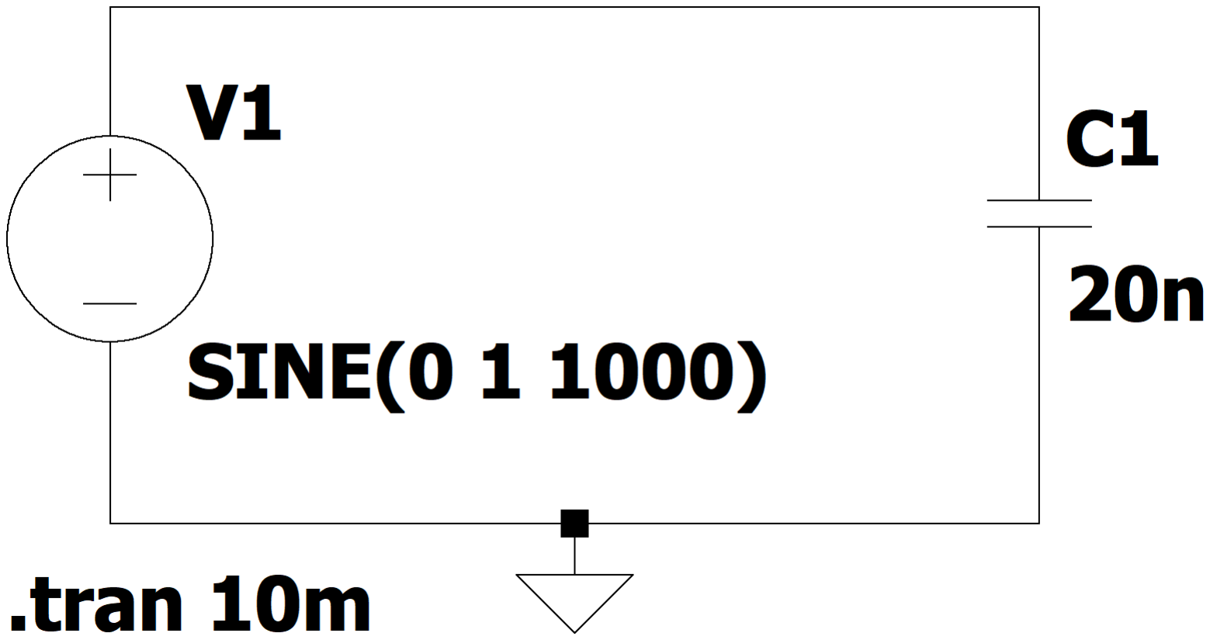
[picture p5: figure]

Figure 2.14: Real capacitor 20 nF in parallel with an ideal AC source Ve

Figure 2.15: Behaviour of the current Ie when a real 20 nF capacitor is connected to an ideal AC source Ve.

### 2.4.1.2 Ideal inductor simulation

In order to simulate a perfect inductor, the resistors R3 and R5 are ketpt equal to 50 Ω.

The value of the inductance can be adjusted using the potentiometer R5. R1 is another

potentiometer used in order to cancel the parallel resistors. So the following condition

must be checked whatever R4 :
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
The equivalent inductor is expressed this way :

Le = R4R5C

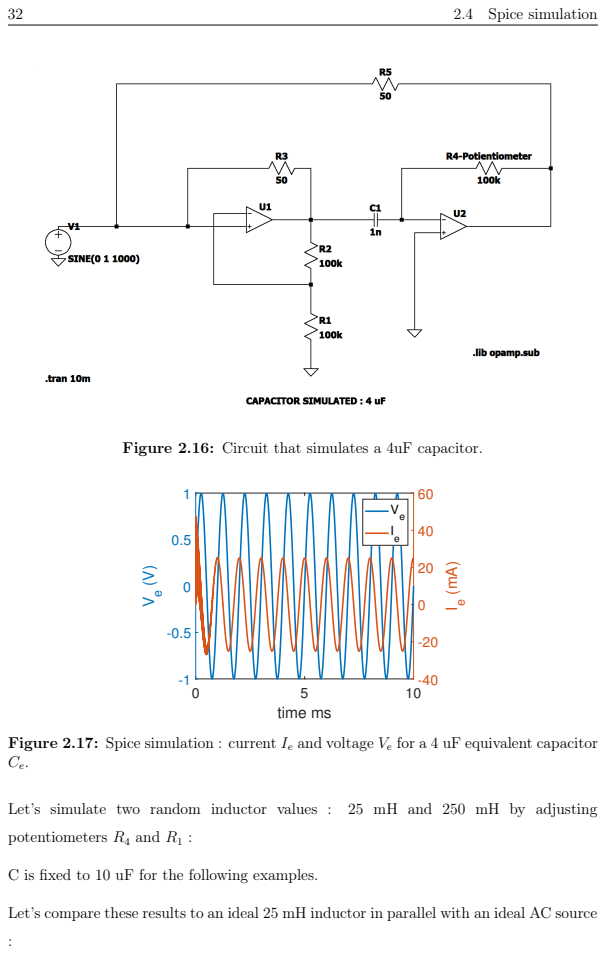
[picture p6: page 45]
2.4 Spice simulation; time ms; potentiometers R4 and R1 :

Figure 2.16: Circuit that simulates a 4uF capacitor.

Figure 2.17: Spice simulation : current Ie and voltage Ve for a 4 uF equivalent capacitor

Let’s simulate two random inductor values : 25 mH and 250 mH by adjusting

C is fixed to 10 uF for the following examples.

Let’s compare these results to an ideal 25 mH inductor in parallel with an ideal AC source

2.4 Spice simulation | 33

Figure 2.18: Real 4 uF capacitor connected in parallel with an ideal AC source Ve.

Figure 2.19: Behaviour of the current Ie when a real 4 uF capacitor is connected to an ideal AC source Ve.

As a result, the source current that is going to the equivalent inductor Le behaves exactly

the same way as for an ideal inductor. Let’s change the value of the inductor Le to 250

mH by adjusting R4 and R1.

Let’s now compare these results to an ideal 250 mH inductor :

As the previous example, the output current Ie of the source is correctly replicated. The

phase shift between the current and voltage is 90 degrees.

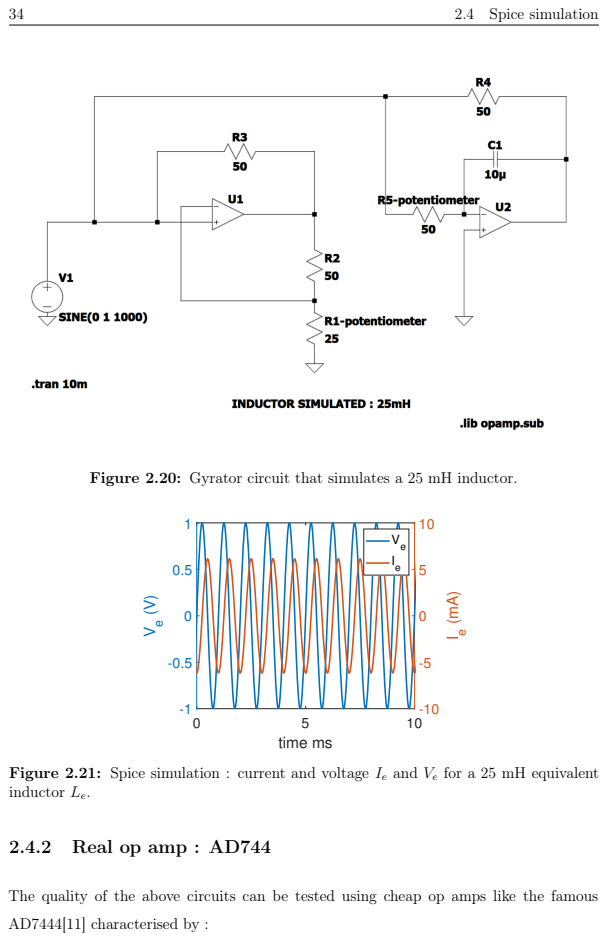
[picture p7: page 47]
2.4 Spice simulation; time ms; AD7444[11] characterised by :

Figure 2.20: Gyrator circuit that simulates a 25 mH inductor.

Figure 2.21: Spice simulation : current and voltage Ie and Ve for a 25 mH equivalent
inductor Le.

2.4.2 Real op amp : AD744

The quality of the above circuits can be tested using cheap op amps like the famous

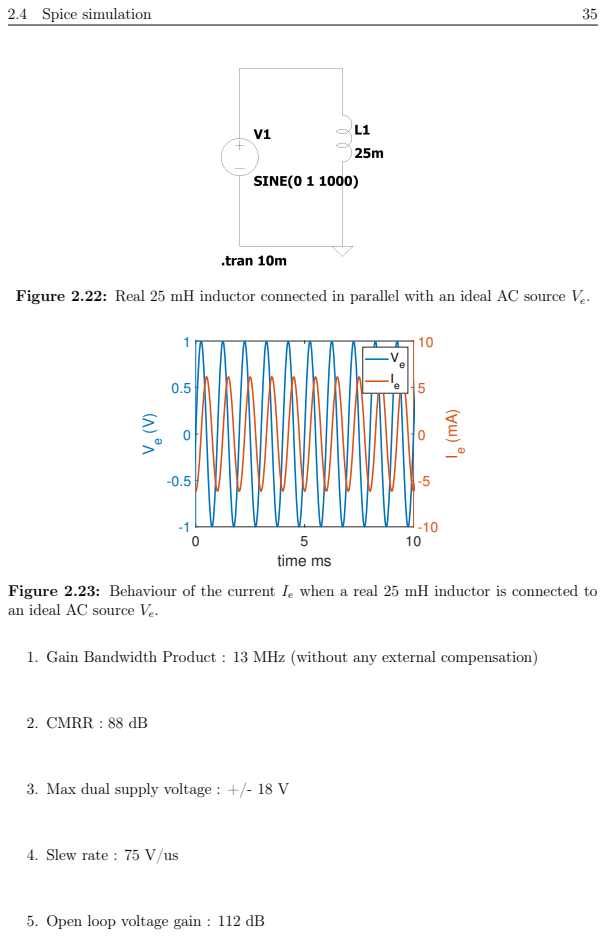
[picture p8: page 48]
2.4 Spice simulation; time ms; 2. CMRR : 88 dB

Figure 2.22: Real 25 mH inductor connected in parallel with an ideal AC source Ve.

Figure 2.23: Behaviour of the current Ie when a real 25 mH inductor is connected to
an ideal AC source Ve.

1. Gain Bandwidth Product : 13 MHz (without any external compensation)

3. Max dual supply voltage : +/- 18 V

4. Slew rate : 75 V/us

5. Open loop voltage gain : 112 dB

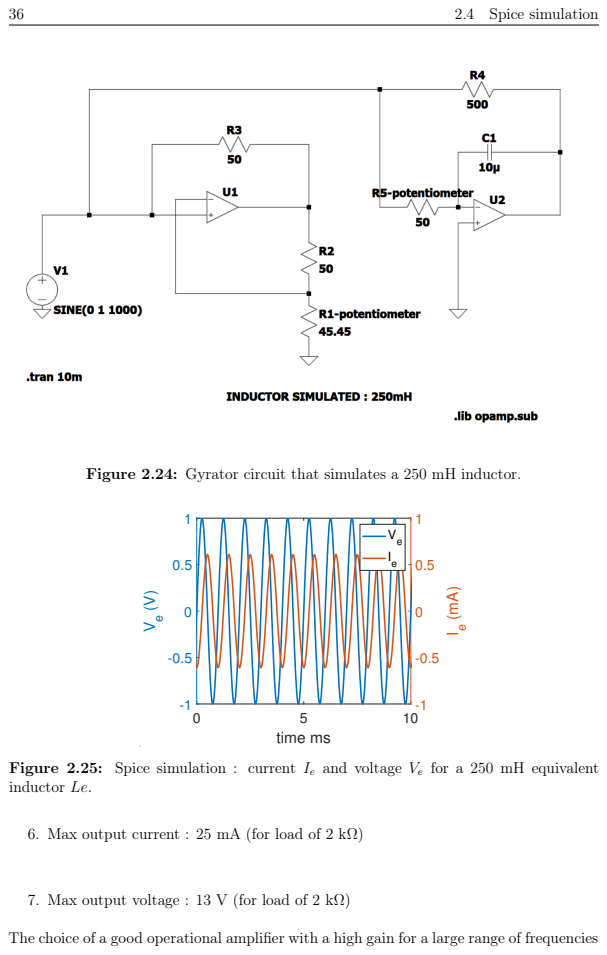
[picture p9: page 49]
2.4 Spice simulation; time ms

Figure 2.24: Gyrator circuit that simulates a 250 mH inductor.

Figure 2.25: Spice simulation : current Ie and voltage Ve for a 250 mH equivalent
inductor Le.

6. Max output current : 25 mA (for load of 2 kΩ)

7. Max output voltage : 13 V (for load of 2 kΩ)

The choice of a good operational amplifier with a high gain for a large range of frequencies

2.4 Spice simulation | 37

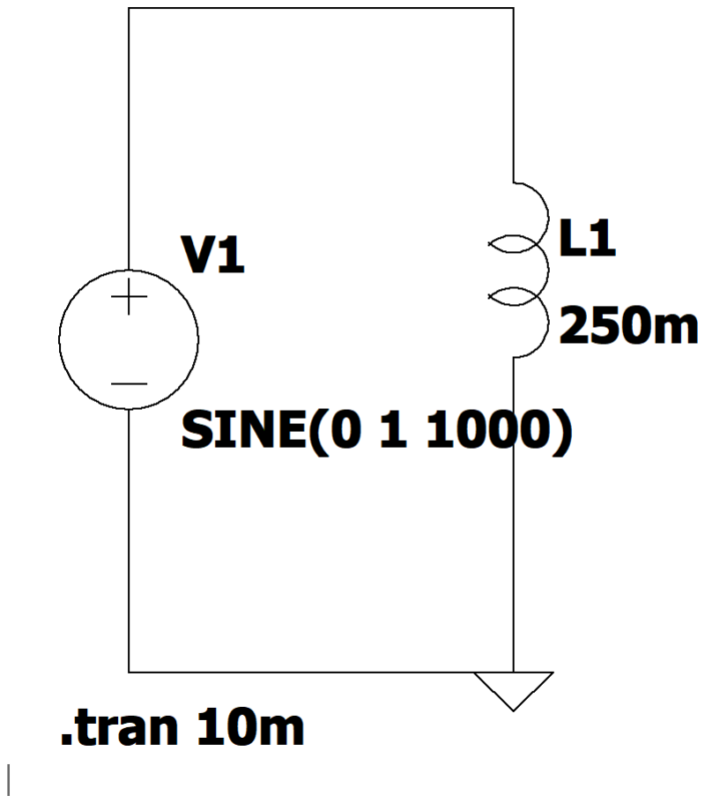
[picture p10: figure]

Figure 2.26: Real 250 mH inductor connected in parallel with an ideal AC source Ve.

Figure 2.27: Behaviour of the current Ie when a real 250 mH inductor is connected to an ideal AC source Ve.

allows us to take advantage of the negative feedback used in the gyrators and previous

circuits (section 3 and 4). The AD744 is highly recommended for designing active filters.

This precision op amp ensures a gain greater than 50 dB until 90 kHz which is suitable

for our application (see Fig10 datasheet AD744). Furthermore, The available range of

38 | 2.4 Spice simulation

frequencies can be extended using external compensators. The main limitation are the

maximum output current and output voltage. So the value of the components around

the op amps have to adjusted such that these limitations are satisfied.

### 2.4.2.1 Ideal capacitor simulation

design of components Based on the results provided in section 2.2.3.4, R2 is chosen

equal to R1. This implies that R3 must be equal to R5 in order to cancel the redundant

parallel resistor thanks to the N.I.C. Choosing R3 and R1 greater than 5000 Ω and
|Yˆ | ≤ 1
5000 allows us to fix the maximum output current of the first op amp to 4 mA.

This is an upper bound that has been exaggerated in order to be sure that the output

current is of the order of 20 mA. We’ll compute later the true maximum once the value

of the capacitor will be fixed.

The frequency should be

f ≤

1
500.2πC

As a reminder, the equivalent capacitance is Ce = 2 R4
R5

C

Concerning the second op amp, If we let R4 going from 50 to 50 kΩ, the following

condition ensures that the maximum output current never exceeds 25 mA (exaggerated

as mentioned previously) :

f ≤

5 × 10−3 −
1
R5
2.2πC(1 + R4
R5

)

Choosing a capacitance value C = 1 nF allows us to work with a maximum frequency of

18 kHz in order to satisfy the output current limitation of the op amp. The capacitance

value can take values on the range : [20 pF, 20 nF]. The potentiometer R4 is used in

order adjust the equivalent capacitance.

2.4 Spice simulation | 39

Furthermore, the output voltage of the AD744 is also limited. So the maximum allowed

frequency is less than 18 Khz. As determined in section 2.2.3.4 (vi), the maximum output

voltage of the op amp should be less than 18 V (saturation voltage):

|Vˆ
s2

| = |Vˆ

e|(1 + R2
R1

)|Yˆ |R4 < 18 V

f < 18
2|Vˆ
| e|R42πC

f < 5730 Hz

So the maximum allowed frequency is in the order of 5 kHz in order to avoid any voltage

saturation of the AD744. This is confirmed by simulation in LT spice.

Spice Simulation of an adjustable capacitor Let’s simulate the following

capacitance and compare it with a real capacitor. The simulation is performed for a

2 nF and a 20 nF equivalent capacitor.

Figure 2.28: Circuit that simulates a 20 nF capacitor using ad744 op amp

0

5

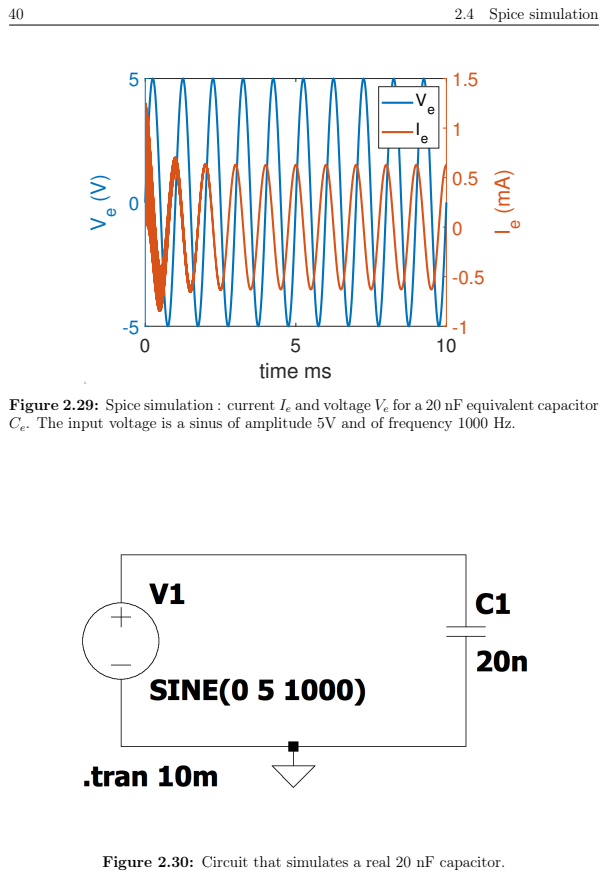
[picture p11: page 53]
2.4 Spice simulation; time ms

Figure 2.29: Spice simulation : current Ie and voltage Ve for a 20 nF equivalent capacitor
Ce. The input voltage is a sinus of amplitude 5V and of frequency 1000 Hz.

Figure 2.30: Circuit that simulates a real 20 nF capacitor.

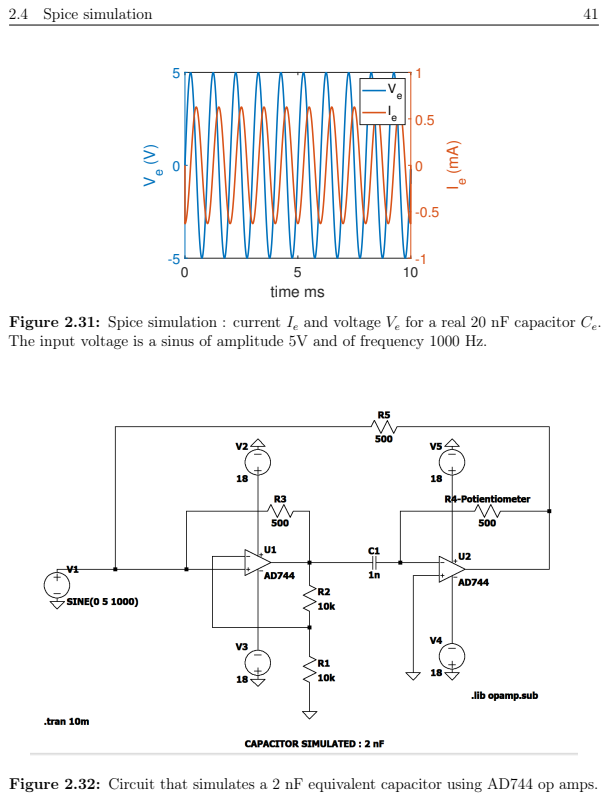
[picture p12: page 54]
2.4 Spice simulation; time ms

Figure 2.31: Spice simulation : current Ie and voltage Ve for a real 20 nF capacitor Ce.
The input voltage is a sinus of amplitude 5V and of frequency 1000 Hz.

Figure 2.32: Circuit that simulates a 2 nF equivalent capacitor using AD744 op amps.

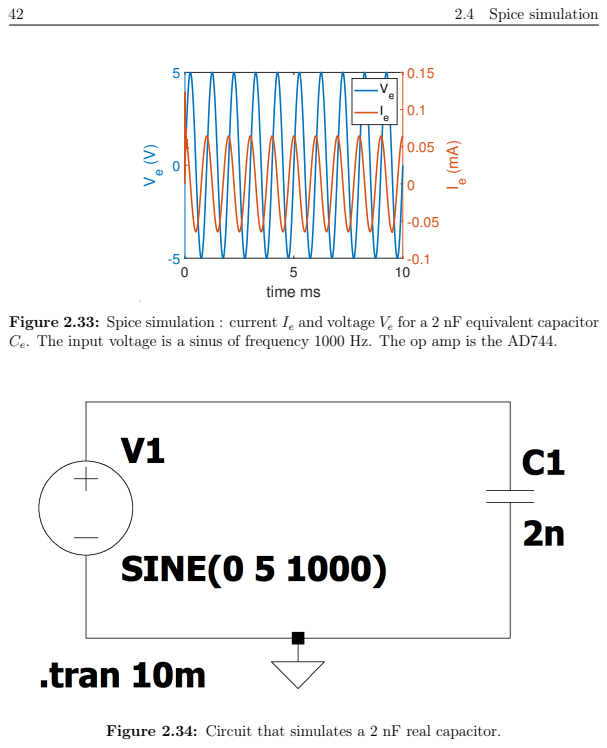
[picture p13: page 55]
2.4 Spice simulation; time ms

Figure 2.33: Spice simulation : current Ie and voltage Ve for a 2 nF equivalent capacitor
Ce. The input voltage is a sinus of frequency 1000 Hz. The op amp is the AD744.

Figure 2.34: Circuit that simulates a 2 nF real capacitor.

2.4 Spice simulation | 43

Figure 2.35: Spice simulation : current Ie and voltage Ve for a real 2 nF capacitor Ce. The input voltage is a sinus of amplitude 5V and of frequency 1000 Hz.

### 2.4.2.2 Ideal inductor simulation

design of components For the sake of simplicity, the resistors R2 and R3 are kept

equal. It results that the following condition must always be satisfied whatever the value

of the potentiometer R4 :
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
So R1 has to be permanently adjusted in order to cancel the parallel resistor term.

Choosing R4 and R5 greater than 1000 kΩ allows us to fix the maximum output current

of the first op amp to 20 mA.

Concerning the second op amp, the fundamental frequency of the input signal must be

greater than a certain threshold in order to make sure that the output current doesn’t

exceed 20 mA :

f ≥

1
1000.2πC

As a reminder : L = R4R5C

Choosing C = 1 uF allows us to have an inductor that ranges from [1, 100H] with a

minimum input frequency of 159 Hz.

Furthermore, the output voltage of the second op amp should stay under its limitation :

44 | 2.4 Spice simulation

|Vˆ
s2

| =

Ve
R4|Yˆ |

< 18 V

f > Ve R42πC

1
18

f > 44 Hz

Spice Simulation of an adjustable inductor As performed for the equivalent

capacitor, the AD744 is used in order to simulate the gyrator. We assume a sinus input

voltage at 1000 Hz. Two inductor values are simulated : 1 Henry and 100 Henry. The

performance of the gyrator is compared with ideal inductors.

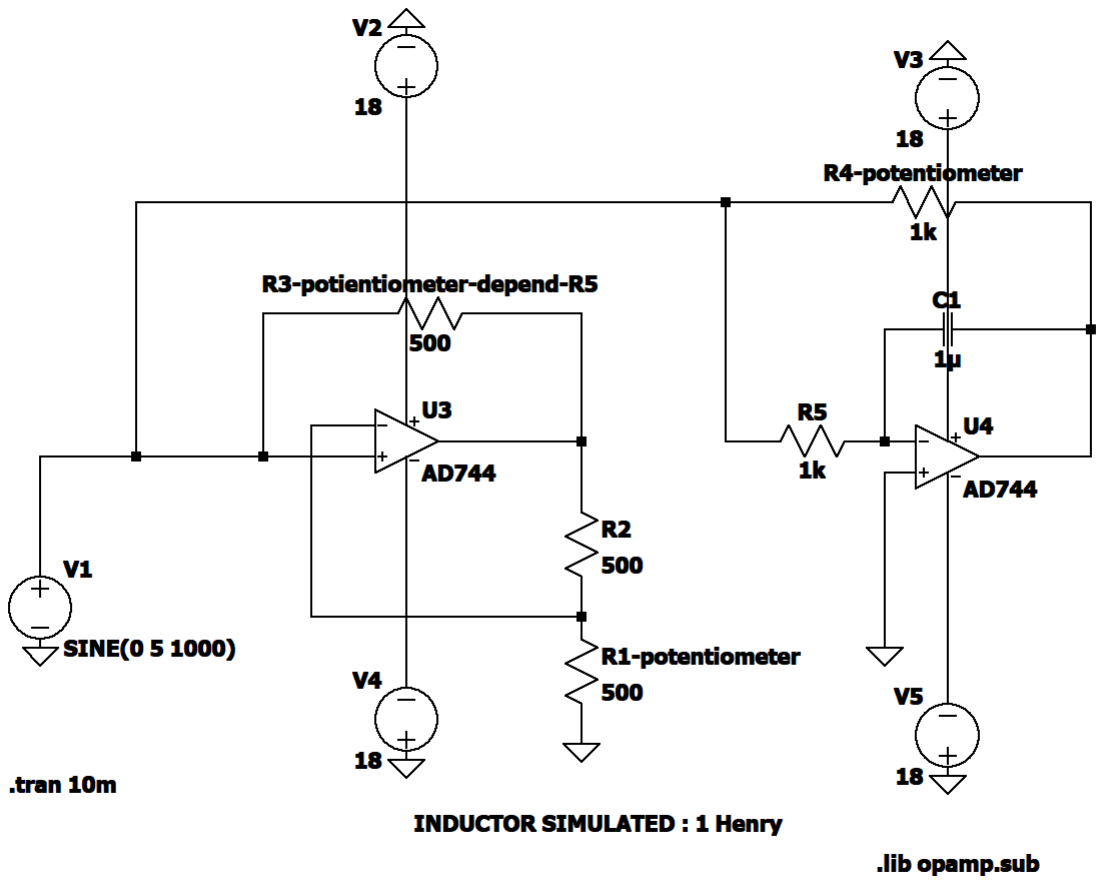
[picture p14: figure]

Figure 2.36: Circuit that simulates a 1 henry equivalent inductor.

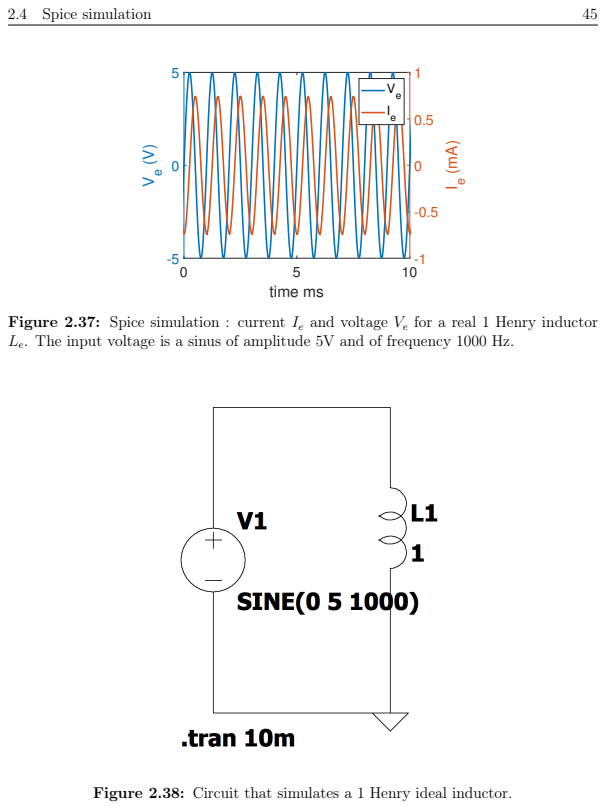
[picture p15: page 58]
2.4 Spice simulation; time ms

Figure 2.37: Spice simulation : current Ie and voltage Ve for a real 1 Henry inductor
Le. The input voltage is a sinus of amplitude 5V and of frequency 1000 Hz.

Figure 2.38: Circuit that simulates a 1 Henry ideal inductor.

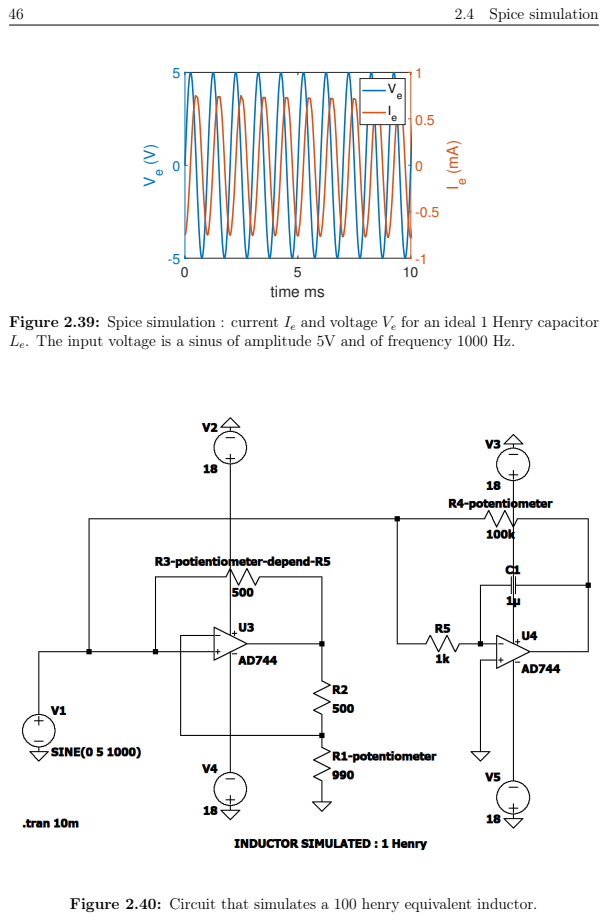
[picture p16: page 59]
2.4 Spice simulation; time ms

Figure 2.39: Spice simulation : current Ie and voltage Ve for an ideal 1 Henry capacitor
Le. The input voltage is a sinus of amplitude 5V and of frequency 1000 Hz.

Figure 2.40: Circuit that simulates a 100 henry equivalent inductor.

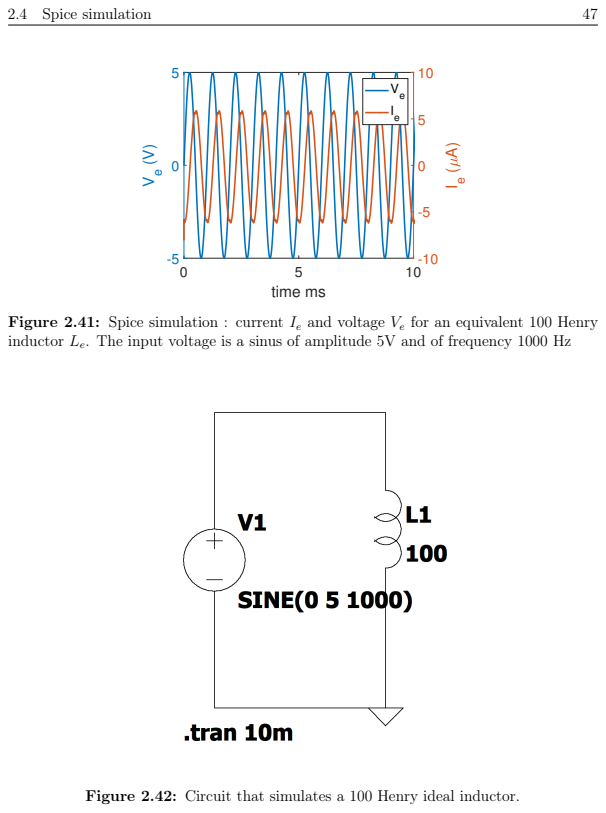
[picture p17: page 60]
2.4 Spice simulation; time ms

Figure 2.41: Spice simulation : current Ie and voltage Ve for an equivalent 100 Henry
inductor Le. The input voltage is a sinus of amplitude 5V and of frequency 1000 Hz

Figure 2.42: Circuit that simulates a 100 Henry ideal inductor.

48 | 2.4 Spice simulation

Figure 2.43: Spice simulation : current Ie and voltage Ve for an ideal 100 Henry capacitor Le. The input voltage is a sinus of amplitude 5V and of frequency 1000 Hz.

### 2.4.2.3 RLC impedance simulation

As a short summary, it’s possible to simulate a RLC impedance using the AD744 op amps

with the following characteristics :

- R ∈ [1, 100 kΩ]
- C ∈ [20 pF, 20 nF]
- L ∈ [1, 100H]
- f ∈ [159 Hz, 5.7 kHz]
- 0V < Vin < 5V

NB : the capacitors are assumed to be ideal (ESR = 0 Ω) The idea is to combine

the gyrator and the capacitor equivalent circuit in order to simulate an "ideal RLC

impedance" by adjusting simple potentiometers.

Let’s simulate a RLC impedance with :

1. R = 1 kΩ

2.4 Spice simulation | 49
2. Ce = 2 nF
3. Le = 2 Henry
4. Input voltage of 5 V of frequency 5000 Hz.

As a reminder, the equivalent capacitance is determined by this expression :

Ce = 2

R4
R5

C

And the equivalent inductance by this expression :

Le = R

′
4R

′
5C

′

But the following condition should always be satisfied in order to cancel the redundant

parallel resistors :
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
R4 is thus adjusted to 5000 Ω in order to have Ce = 2 nF and R′ 4 = 2 kΩ with R1 = 666

Ω in order to get Le = 2 H.

50 | 2.4 Spice simulation

Figure 2.44: RLC impedance simulated using the ad744 op amps. The amplitude of the sinus input voltage Ve is set to 5V and the corresponding frequency is 3000 Hz. Le = 1 H, Ce = 2 nF and R = 50 kΩ.

Figure 2.45: Spice simulation : current Ie and voltage Ve for Le = 1 H, Ce = 2 nF and R = 50 kΩ. The input voltage is a sinus of amplitude 5V and of frequency 3000 Hz.

There is a small transient response for the simulated RLC impedance. After 0.3 ms, the

high frequency oscillation is attenuated. The performance of the RLC impedance made

of op amps can be compared to an ideal RLC impedance.

2.4 Spice simulation | 51

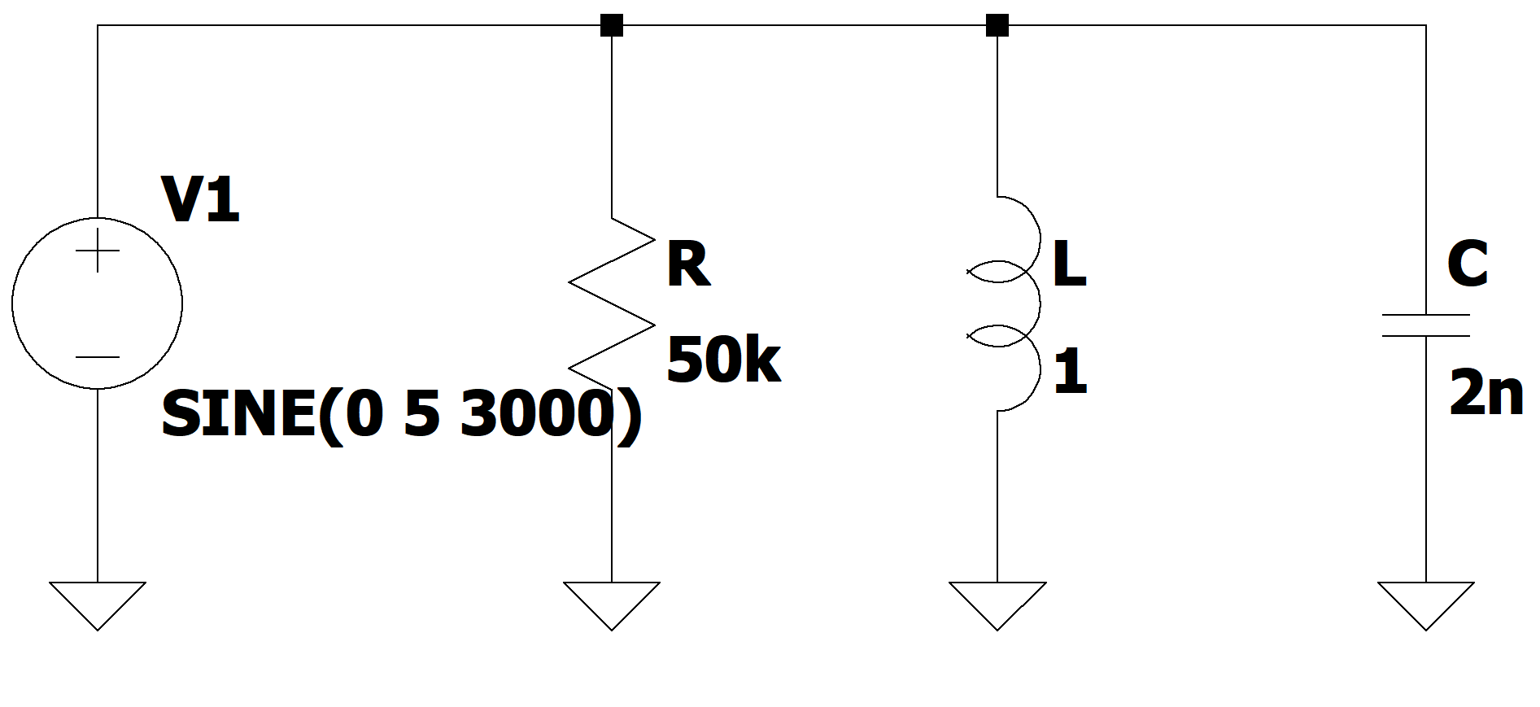
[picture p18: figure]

Figure 2.46: ideal RLC impedance with L = 2 H, C = 2 nF and R = 1 kΩ.

Figure 2.47: Spice simulation : current Ie and voltage Ve for L = 2 H, C = 2 nF and R = 1 kΩ. The input voltage is a sinus of amplitude 5V and of frequency 5000 Hz.

As can be observed in plot 4.34 and plot 4.36, the two outputs current delivered by the

source Ve share the same global behaviour. The peak output current is around 5 mA.

And the phase shift between the voltage and current is the same.

### 2.4.2.4 Switched RC-RL impedance

In some applications, simulating a RLC parallel impedance is not useful. By using a

switch between the RC and RL impedance, the user is free to simulate either an inductive

(in case of a motor for example) or a capacitive impedance. This will allow the user to

increase the available bandwidth frequency without risk of saturation of the op amps. If

52 | 2.4 Spice simulation

the user tries to simulate a RC capacitive load, he will only be limited at high frequencies

(risk of voltage saturation of the opamp since the ideal capacitor would act as a "short-

circuit"). But he won’t be limited at low frequencies. On the other hand, if the user

desires to simulate an RL inductive load, he will only be limited at low frequencies (risk

of current saturation at very low frequencies since the ideal parallel inductor would act

like a "short-circuit").

Figure 2.48: Ideal switching RL-RC impedance. The user is free to choose the phase between [-90°, 0°] by activating the RC load or between [0°, 90°] by activating the RL load.

This allows us to simulate a parallel switched RC - RL impedance with the following

characteristics :

RC impedance

- R ∈ [1, 100 kΩ]

2.4 Spice simulation | 53
- C ∈ [20 pF, 20 nF]
- f ∈ [0 Hz, 5.7 kHz] (for the highest capacitor value).
- 0V < Vin < 5V

RL impedance

- R ∈ [1, 100 kΩ]
- L ∈ [1, 100H]
- f ∈ [159 Hz, +∞]
- 0V < Vin < 5V

This switching RC-RL impedance will be implemented in hardware in the CSL laboratory

using the LM324 op amps. The obtained results will be discussed in the next section.

54 | 2.5 Practical implementation of the analog RLC impedance in the CSL lab

## 2.5 Practical implementation of the analog RLC

## impedance in the CSL lab

This section is dedicated to the practical implementation of the RLC impedance. The

op amps used are the LM324[12] (provided by the CSL). This component consists of

four independent operational amplifiers (two for the capacitor simulator and two for the

inductor simulator). There are characterised by :

1. Gain Bandwidth Product : 1.3 MHz
2. CMRR : 80 dB
3. Max dual supply voltage : +/- 16 V
4. Typical Slew rate : 0.4 V/us (slow compared to the AD744 described in the

previous section)

5. Open loop voltage gain : 100 dB
6. Max output current : 70 mA (for load of 2 kΩ) and 40 mA DC
7. Max output voltage : 13 V (for load of 2 kΩ)

The objective of this section is to compare the simulated results on LT Spice with those

obtained from the real hardware implementation. The different values of the capacitor

compared are : 2nF, 20 nF. On the other hand, the inductor values compared are 100

mH and 1 H.

2.5 Practical implementation of the analog RLC impedance in the CSL lab | 55

### 2.5.1 Equivalent capacitor

Figure 2.49: Circuit that simulates an ideal capacitor using the LM324 op amp.

The value of the capacitor can be adjusted using the potentiometer R4. The frequency of

the input signal shouldn’t exceed 4000 Hz in order to prevent from any voltage saturation.

The allowed capacitance values are between [20 pF, 20 nF]. Increasing it too much will

lead to a voltage saturation as already shown in previous sections.

56 | 2.5 Practical implementation of the analog RLC impedance in the CSL lab

2.5.1.1 2 nF capacitor

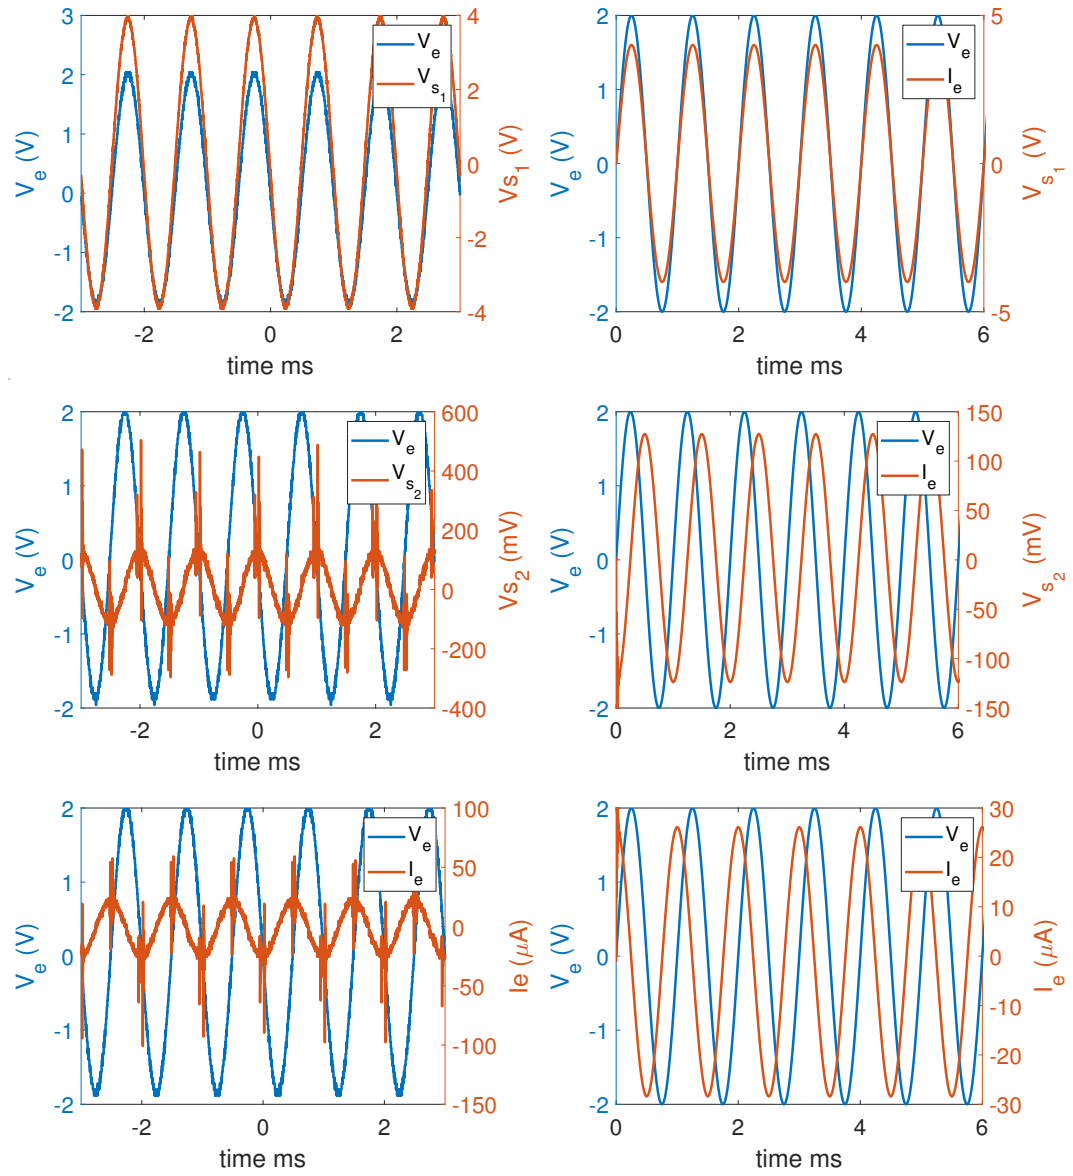
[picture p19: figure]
time ms

Figure 2.50: Capacitor simulated : 2 nF. These plots compare the characteristics of the hardware implementation (on the left-hand side) and the spice simulation (on the right-hand-side) in terms of the output voltage (Vs1

) of the first op amp, the output voltage (Vs2

) of the second op amp and the output current of the source generator (Ie).

Concerning the output voltage of the fist op amp (N.I.C circuit), the results obtained

theoretically (confirmed by the LT spice simulation) match perfectly with the hardware

implementation.

As demonstrated in subsection (2.2.3.4) the amplitude of the output voltage Vs1 should

2.5 Practical implementation of the analog RLC impedance in the CSL lab | 57

be equal to :

|Vˆ
s1

| = |Vˆ

e|(1 + R2
R1

) = 4 V

Similarly, Vs2
should be equal to :

|Vˆ
s2

| = |Vˆ

e|(1 + R2
R1

)wCR4 = 125 mV

The fundamental frequency of the output voltage Vs2

is a sinus of amplitude 125 mV. But

the signal is affected by high-frequency noise. The THD (total harmonic distortion) is

0.22 % and the SNR is 8.48 dB (quite low). The response at the output of the op amp

will unfortunately affect the output current of the generator (Ie).

Figure 2.51: FFT of the output current (Ie) from the hardware implementation.

As can be seen from the above figure, the main component of the Fourier transform is

at 1 kHz. This one is polluted by high frequency noise (above 10 kHz). The low SNR is

due to the small CMRR (60 dB at 1 kHz). Furthermore, the LM324 is not a precision

op amp (it’s a kind of "general-purpose op amp"). The phase shift between the output

current ˆIe and the input voltage Vˆ
e is 90 °. This comforts our motivation to build a "pure"

capacitor.

58 | 2.5 Practical implementation of the analog RLC impedance in the CSL lab

2.5.1.2 20 nF capacitor

Figure 2.52: Capacitor simulated : 20 nF at 1000 Hz. These plots compare the characteristics of the hardware implementation (on the left hand side) and the spice simulation (on the right-hand side) in terms of the output voltage (Vs1

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

For the 20 nF simulated capacitor, the obtained results from the hardware implementation

are still polluted by high frequency noise. The main component of the signal is at 1000

Hz and matches well the simulated results on LT spice. The values can be verified

2.5 Practical implementation of the analog RLC impedance in the CSL lab | 59

theoretically as described in section (2.2.3.4). It can be noticed that there is a phase shift

of 90°between the output current ˆIe and input voltage (Vˆ

Figure 2.53: FFT of the output current (Ie) from the hardware implementation.

### 2.5.1.3 Frequency analysis

Let’s study the frequency behaviour (small signal AC analysis) of this circuit for different

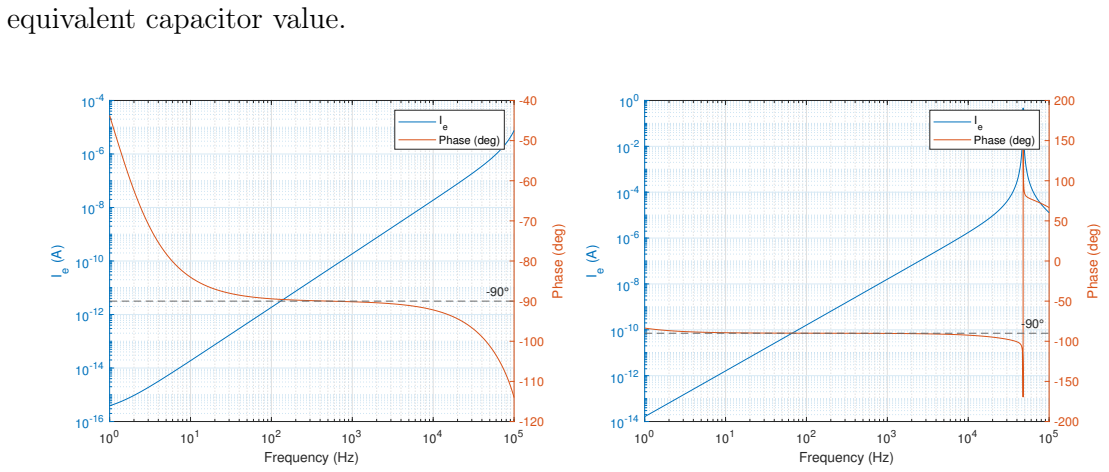
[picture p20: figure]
equivalent capacitor value.; Frequency (Hz); Phase (deg)

Figure 2.54: Frequency response of the equivalent capacitor circuit (with LM324 op amps) for different capacitor values : 2 nF (left figure), 20 nF ( right figure). Small signal analysis with amplitude 1 Volt.

The two main following criteria are used in order to assess the performance of the

equivalent capacitor circuit :

60 | 2.5 Practical implementation of the analog RLC impedance in the CSL lab
1. The bandwidth frequency for which the phase is near -90°"called the 90-degree-

bandwidth". In this region, the phase of the input voltage Vˆ
e is phase shifted to

-90°with respect to the output current ˆIe. The equivalent is ideal.

2. The output current Ie should increase linearly with the frequency with slope (wC).

As can be seen from the above figure, the output current increases linearly with frequency

specially in the 90-degree-bandwidth. Furthermore, this bandwidth becomes larger if the

equivalent capacitor if the equivalent capacitor is higher.

### 2.5.2 Equivalent inductor

Figure 2.55: Circuit that simulates an ideal inductor using the LM324 op amp.

The value of the equivalent inductor can be adjusted using the potentiometer R5. The

frequency of the input signal shouldn’t be less than 160 Hz in order to prevent from

any current saturation. The potentiometer R1 allows cancelling the parallel resistor in

2.5 Practical implementation of the analog RLC impedance in the CSL lab | 61

order to get an ideal inductor. The allowed inductor values are between [1 H, 100 mH].

Decreasing it too much will lead to a current saturation (for small frequencies). The

input signal frequency is set to 500 Hz by default in order to study its behaviour.

2.5.2.1 100 mH inductor

In order to get an 100 mH equivalent inductor, the potentiometer R5 is set to 100 Ω. The

potentiometer of the N.I.C R1 is adjusted to 90 Ω to cancel the parasitic parallel resistor.

62 | 2.5 Practical implementation of the analog RLC impedance in the CSL lab

Figure 2.56: Inductor simulated : 100 mH. These plots compare the characteristics of the hardware implementation (on the left hand side) and the spice simulation (on the right-hand side) in terms of the output voltage (Vs1

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

Since the value of the chosen inductor is below its minimum (1 H), the first op amp

(N.I.C circuit) saturates at +/- 11 V. It’s important to notice that the LM324 is not a

rail-to-rail op amp and then saturates far below the power supply voltage (+/-16 V).

If the op amp was ideal, the output voltage V s1 should be equal to (see section 3.2.1.4) :

2.5 Practical implementation of the analog RLC impedance in the CSL lab | 63

|Vˆ
s1

| = |Vˆ

e|(1 + R2
R1

) = 13.1 V

One can suggests that this issue can be solved by reducing the value of the resistor R2

(and hence R3 since they should be equal as described in section 3.3.1). Choosing R2(i.e

R3) to 100 Ω will lead to an amplitude output voltage |Vˆ
s1

| = 4 V. This way, we make sure

that the first op amp associated to the N.I.C won’t saturate. Unfortunately, a current

saturation occurs instead. The output current ˆIs2
is equal to:

ˆIs2 =

Vˆ
s1
R1

(1 + R2
R3

) = 44.4 mA

On the other hand, the output voltage Vˆ
s2 of the second op amp matches well with the

simulated results. It has been shown (section 3.3.1.4) mathematically that :

|Vˆ
s2

| =

|Vˆ
e|
wCR4

= 636 mV

Since the first op amp saturates, the output current of the generator ˆIe is distorted. The

fundamental frequency remains at 500 Hz. It can also be noticed that the main fourier’s

component of the output current is phase shifted by -90°.

Figure 2.57: FFT of the output current (Ie) from the hardware implementation.

As can be seen from the above figure, the fft of the output current Ie shows that the main

64 | 2.5 Practical implementation of the analog RLC impedance in the CSL lab

component remains at 500 Hz. There are some harmonics due to the saturation of the

first op amp. The total harmonic distortion (THD) is 8.6%. The SNR is low : 21.59 dB.

2.5.2.2 1 H inductor

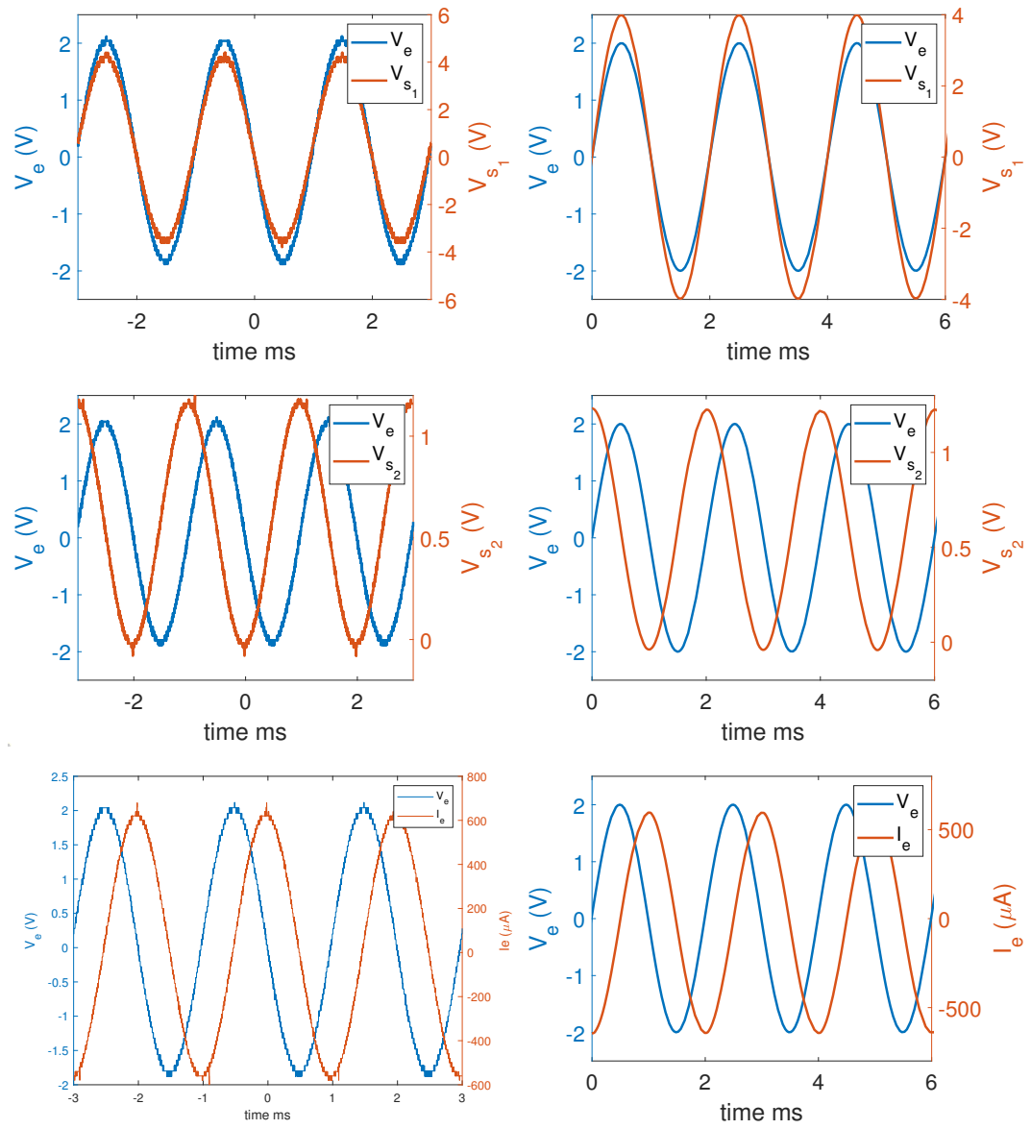
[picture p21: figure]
time ms

Figure 2.58: Inductor simulated : 1 H. These plots compare the characteristics of the hardware implementation (on the left hand side) and the spice simulation (on the right-hand side) in terms of the output voltage (Vs1

) of the first op amp, the output voltage (Vs2

) of the second op amp and the output current of the source generator (Ie).

2.5 Practical implementation of the analog RLC impedance in the CSL lab | 65

For the 1 H simulated inductor, the obtained results from the hardware implementation

matches well with the simulated results on LTspice. The values can be verified

theoretically as described in section (2.2.3.4). It can be clearly seen from the above

figure that there is a phase shift of -90°between the output current ˆIe and the input

voltage Vˆ
e.

Figure 2.59: FFT of the output current (Ie) from the hardware implementation.

The fourier’s transform of the output current Ie shows a single nice fringe located at 500

Hz. There’s no harmonic distortion and the signal is not polluted by high frequency noise.

### 2.5.2.3 Frequency analysis

Let’s now study the frequency behaviour (small signal AC analysis) of the gyrator

for different equivalent inductor values. The LM324’s are still used for the gyrator

implementation.

66 | 2.5 Practical implementation of the analog RLC impedance in the CSL lab

Phase (deg) Figure 2.60: Frequency response of the gyrator circuit (with LM324 op amps) for

different inductor values : 10 mH (top left figure), 100 mH (top right figure) and 1 H (last figure). Small signal analysis with amplitude 1 Volt.

As mentioned previously for the equivalent capacitor circuit (subsubsection 5.1.3) One of

the main criteria to evaluate the quality of the gyrator circuit is the phase shift between

the output current ˆIe and the input voltage Vˆ
e. A phase shift of 90°means that an ideal

inductor is simulated by the circuit. This means that the N.I.C plays well its role and no

current/voltage saturation occurs at the output of the LM324 op amps. The bandwidth

frequency for which the phase is near 90°"called the 90-degree-bandwidth" is a good

2.5 Practical implementation of the analog RLC impedance in the CSL lab | 67

indicator of the equivalent inductor perfomance. The larger the 90-degree-bandwidth is,

the more accurate it is (no distortion or saturation). It can clearly be seen from the above

figures that this bandwidth increases with the chosen inductor values. Furthermore,

there exists a cut off frequency where the circuit becomes unstable (2 kHz).

The second criterion is the linear (log-scale : warning !) behaviour of the output current

with respect to the frequency. For a perfect inductor, the output current Ie should

decrease with slope 1/(wL) for given input voltage. This is confirmed by the above

figures. Ie decreases linearly (log scale) wrt to frequency inside the 90-degree-bandwith.

### 2.5.3 Discussion

As mentioned in previous sections, the main limitations are the maximum output

voltage/output current. They reduce the frequency range for which the equivalent

capacitor/inductor behaves like real components. For the capacitor, a voltage or current

saturation occurs if the frequency of the input signal is to high. On the other hand,

if the frequency of the input signal is too low (DC), the ideal inductor behaves as a

short-circuit. This leads to a voltage/current saturation.

Using power op amps may improve the 90-degree-bandwidth since they tolerate high

output voltage and output current. The OPA548[13] is a good choice here because it

allows a maximum output current of 5 amps (the output is internally buffered) and the

voltage saturation occurs above 30 V.

As with any op amp circuit, the performance of of gyrators at high frequencies depends

on the op amp bandwidth. So a gyrated inductor/capacitor will stop looking like an

inductor/capacitor at frequencies greater than a few percent of the op amp bandwidth

(see [14] for more information).The simulation results in figure 5.12 show the behaviour

of the gyrated inductor wrt to frequency. Roughly speaking, the nearly perfect inductor

(at low frequencies) becomes a capacitor at high frequencies with a resonance in between.

This may appear quite nasty but notice that the inductor has an impressive high quality

68

factor of about 6000 at 1 kHz (for Lequiv = 1 Henry) assuming that the ESR of the gyrated

inductor is 1 Ω. So the third criterion that should be considered is the gain bandwidth

product (GBW). A higher GBW means greater loop gain, and higher loop gain means

lower error (gain, phase, distortion). Since the op amps of the N.I.C and the gyrator are

used with the negative feedback, the open loop should stay high enough to make sure

that the inverting and the non-inverting input stays at same potential : V

+ = V

−.

# 3 Digital implementation

## 3.1 Schematic overview

Figure 3.1: Schematic of the digital implementation of the RLC impedance.

3.2 Digital RLC filter | 69

Let’s consider a continuous input voltage v(t). This one has to be sampled at sampling

period Ts by the microcontroller. Assuming that the microcontroller cannot afford

to take as input a negative voltage (most general case), the input voltage has to be

rectified. The sign of v(t) has to be adjusted digitally inside the microcontroller after

the analog-to-digital converter. The voltage is quantized with N bits and fed into a

RLC filter. The digital implementation of the RLC filter will be described in the next

section. The RLC filter outputs an "image" of the quantized output current iQ[n].The

output current is then converted to analog through the DAC [15] (k bits accuracy). It’s

important to notice that the output current is in fact represented by a voltage (which

is an image of the output current). Finally, the voltage reflecting the output current is

converted into current by a voltage-to-current converter after some gain adjusting and

low-pass filtering to remove the noise quantization. The output current is injected into

the generator and the loop is closed.

Here’s more a simplified schema of the digital implementation :

By correctly adjusting Vcontrol(t) according to the value of the inductor or capacitor, it’s

possible to simulate an inductive/capacitive load across the generator. Let’s study in the

next section how Vcontrol(t) can be derived from digital filtering.

## 3.2 Digital RLC filter

Let’s first focus on the most important part : the digital implementation of the RLC

filter. As performed for the analog impedance, the parallel RLC impedance will be first

simulated.

### 3.2.1 Time domain

### 3.2.1.1 Continuous time domain

Let’s consider a continuous input voltage v(t), the current across the resistor can be

computed by the Ohm’s Law :

70 | 3.2 Digital RLC filter
Figure 3.2: Simplified representation of the digital implementation. | The current
injected to the generator is controlled by the microcontroller. It’s proportional to the current that would flow into an inductor or capacitor.

ˆiR =

v(t)
R

(i)

The current across the capacitor is :

iC(t) = C

dv(t)
dt | (ii)

The current across the inductor is such that :

diL(t)
dt =

v(t)
L

(iii)

3.2 Digital RLC filter | 71

For a RC parallel load, the total current can be expressed as

iRC(t) = iR(t) + iC(t) = v(t) R

+ C

dv(t)
dt | (iv)

For the RL parallel load, the total current can be expressed as :

iRL(t) = iR(t) + iL(t) = v(t) R

+

1
L

∫ t

t0

v(t)dt | (v)

### 3.2.1.2 Discrete time domain

Let v[n] be the sampled input voltage at sampling period Ts. The current across the

resistor is
iR[n] = v[n]
R

(vi)

The derivative term associated to the capacitor can be descretized this way :

iC[n] = C
Ts
(v[n] − v[n − 1]) | (vii)

The integrative term associated to the inductor can alsO be decretized :

iL[n] = iL[n − 1] + 1
L
Tsv[n − 1] | (viii)

For a RC parallel load, the total current can be expressed as

iRC[n] = iR[n] + iC[n] = v[n] R

+

C
Ts
(v[n] − v[n − 1]) | (ix)

Similarly, for a RL parallel load, the total current can be expressed as :

iRL[n] = iR[n] + iL[n] = v[n] R

+ iL[n − 1] + 1
L
Tsv[n − 1] | (x)

The two expressions (ix), (x) will be implemented in the microcontroller.

Let’s plot the discrete output current generated by our digital implementation and

72 | 3.2 Digital RLC filter

compare with the continuous output current. 2

Figure 3.3: Simulated capacitor : 1 mF. Left plot : continuous output current. Right plot : discrete output current generated by the microcontroller at sampling frequency 5000 Hz. The input voltage is a 100 Hz sine wave.

Figure 3.4: Simulated inductor : 1 mH. Left plot : continuous output current. Right plot : discrete output current generated by the microcontroller at sampling frequency 5000 Hz. The input voltage is a 100 Hz sine wave.

cfr LTspice digital circuit named "DIGITAL RLC FILTER" to test the performance of

the digital implementation. Change various parameters such as the value of the capacitor,

inductor, sampling frequency, frequency of the input signal, ... And see what happens ...

The discrete output current that has been generated by the microcontroller can be low-

filtered in order to remove the noise due to the sampling frequency. However, it may add

an additional phase shift to the output current and the 90 degree phase shift between

the input voltage and output current may not be satisfied. A low pass filter should be

considered if the magnitude of the output current only matters. Otherwise, the cutoff

2LtSpice is used for the simulations. See [16] for discrete implementations on LtSpice.

3.2 Digital RLC filter | 73

frequency should be set far way from the fundamental frequency of the input voltage.

This will be discussed in the frequency domain section.

### 3.2.2 Frequency domain

The transfer function between the input voltage and the output current can be computed

for the two domains :

- Laplace domain : associated to the continuous time.
- Z-domain : associated to the discrete time. More useful here since a discrete filter

will be implemented.

A frequency analysis can be performed by studying the transfer functions.

### 3.2.2.1 Laplace Transform

The current across the resistor is :

ˆIR(s) = Vˆ (s)

R

(xi)

The current across the capacitor is :

ˆIC(s) = sCVˆ (s) | (xii)

The current across the inductor is :

ˆIL(s) = V (s)
sL

(xiii)

For the RC parallel load, the output current in the Laplace domain can be expressed as :

ˆIRC(s) = Vˆ (s)

R

+ sCVˆ (s) | (xiv)

For a RL load :

74 | 3.2 Digital RLC filter

ˆIRL(s) = Vˆ (s)

R

+

V (s)
sL

(xv)

The transfer function HRC(s) between the input voltage and the output current can be

deduced :

Hˆ

RC(s) = hatIRC(s)
V (s)

=

1
R
+ sC | (xvi)

Similarly for the inductive load, the transfer function HRL can be expressed as :

Hˆ
RL(s) =

ˆIRL(s)

V (s)

=

1
R

+

1
sL

(xvii)

The continuous transfer functions Hˆ

RL and Hˆ
RC are the equivalent admittance (in

Siemens).

Let’s study the transfer functions in the Laplace domain and Z-domain. The RL and RC

filters will be analysed in the frequency domain using the bode plot.

RC filter

Magnitude (dB); Phase (deg); Bode Diagram; Frequency (Hz)

Figure 3.5: Bode plot of a continuous ideal capacitor (1 mF).

3.2 Digital RLC filter | 75

The above figure shows the main characteristics of continuous RC filter :

- Increasing linear gain (log-scale) with frequency.
- Constant 90° phase shift.

It will be shown in the next subsection that those two characteristics will be altered in

the digital domain. The main limitation will be the sampling frequency.

RL filter

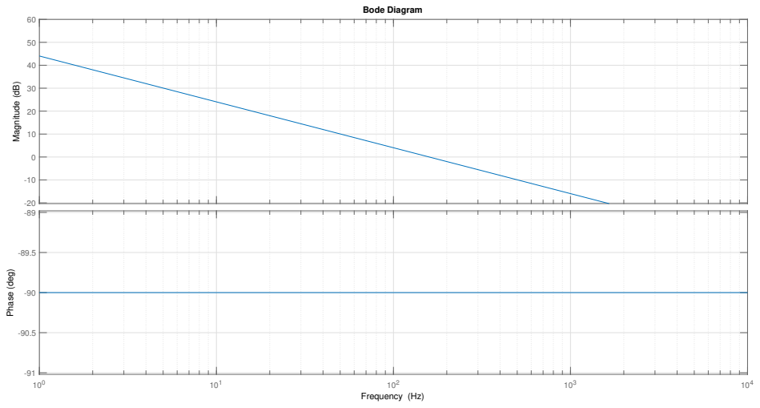
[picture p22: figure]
Magnitude (dB); Phase (deg); Bode Diagram; Frequency (Hz)

Figure 3.6: Bode plot of a continuous ideal inductor (1 mH).

As performed for the RC filter, it can be deduced that :

- Decreasing linear gain with frequency (log-scale).
- Constant -90° phase-shift.

### 3.2.2.2 Z-transform

The current across the resistor is :

ˆIR(z) = Vˆ (z)

R

(xviii)

76 | 3.2 Digital RLC filter

The current across the capacitor is :

ˆIC(z) = C
Ts

Vˆ (z)(1 − z
−1
) | (xix)

The current across the inductor is :

ˆIL(z) = 1
L

Ts

V (z)z

−1
1 − z

−1

(xx)

For the RC parallel load, the output current in the Laplace domain can be expressed as :

ˆIRC(z) = Vˆ (z)

R

+

C
Ts

Vˆ (z)(1 − z
−1
) | (xxi)

For the RL load :

ˆIRL(z) = Vˆ (z)

R

+

1
L

Ts

V (z)z

−1
1 − z

−1

(xxii)

The transfer function HRC(z) between the input voltage and the output current can be

deduced :

Hˆ
RC(z) =

ˆIRC(z)

V (z)

=

1
R

+

C
Ts

(1 − z

−1
) | (xxiii)

Similarly for the inductive load, the transfer function HRL(z) can be expressed as :

Hˆ
RL(z) =

ˆIRL(z)

V (z)

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
1 − z

−1

(xxiv)

Let’s study the two transfer functions Hˆ

RL and Hˆ
RC in the Z-Domain. Let’s take R

close to ∞ in order to simulate an ideal capacitor and inductor. Since the signal is

discrete in the Z-Domain, the transfer function depends on the sampling frequency. The

analog to digital conversion is limited to 10 kSamples per second (100 µs to perform one

conversion). The digital filter requires 77 µs for each sampling period. This limits the

maximum sampling frequency to 5600 Hz.

3.2 Digital RLC filter | 77

Digital RC filter

Figure 3.7: Bode plot of the digital ideal capacitor (1 mF) transfer function for different sampling frequency : F s1, F s2,F s3, F s4 and F s5 respectively equal to 1, 2, 3, 4 and 5 kHz.

As can be seen from the above figure, the behaviour of our digital filter is strongly

linked to the sampling frequency. The greater the sampling frequency, the larger can

be the input signal bandwidth. The filter stops being stable at half the sampling

frequency. Furthermore, the magnitude response and the phase doesn’t behave the

same way at half the sampling frequency. In fact, the phase decreases much faster

than the gain which limits the available frequency bandwidth of the input signal if we

want to simulate an ideal capacitor with 90° phase-shift. On the other hand, the gain

is less impacted by the frequency. This one stays nearly linear until the Nyquist frequency.

As said previously, since the maximum sampling frequency is limited to 5600 Hz, the

maximum frequency of the input signal shouldn’t exceed half the sampling frequency.

The available frequency bandwidth is limited depending on the degree of importance

is granted to the phase shift. If one considers that the 90° phase shift doesn’t matter,

the available frequency bandwidth can be extended until the Nyquist frequency since the

gain remains linear. This amounts to simulate an ideal capacitor in terms of gain without

taking care of the 90°phase shift. Furthermore, an analog low pass filter can be designed

78 | 3.2 Digital RLC filter

in order to keep only the signal below the sampling frequency without being afraid of the

consequence on the phase-shift. On the other hand, if both gain and phase-shift matter,

the available frequency bandwidth becomes narrower (for a given sampling frequency).

And using a low-pass filter becomes less attractive due to the potential phase-shift it can

produce.

Digital RL filter

Figure 3.8: Bode plot of the digital ideal inductor (1mH) transfer function for different sampling frequency : F s1, F s2,F s3, F s4 and F s5 respectively equal to 1, 2, 3, 4 and 5 kHz.

For the discrete RL filter in the frequency domain : same comment as above (about the

discrete RC filter). Two main differences can be noticed :

1. The gain now decreases linearly (Log-scale!) with respect to the frequency until the

Nyquist frequency. Logical since the filter is inductive.

2. The phase-shift is now -90° between current and voltage (far away from the Nyquist

frequency).

3.3 Hardware part of the digital implementation | 79

## 3.3 Hardware part of the digital implementation

A digital implementation doesn’t always refer to a fully digital circuit. Some high stage

analog circuits are used in order to relieve the microcontroller from power operations.

Several analog stage have to be implemented in order to manage properly data gathering

from the microcontroller. The digital implementation must be embedded in a hardware

part. Let’s enumerate the four analog blocks :

1. Voltage rectifier : rectifies the input voltage because the microcontroller can’t afford

a negative voltage.

2. Comparator : if the input voltage becomes negative, alert the microcontroller !
3. Voltage follower : it’s high input impedance reliefs the microcontroller from

dissipating power.

4. Howland current source : converts controlled voltage to current.

### 3.3.1 Voltage rectifier

Since the microcontroller (ATMEGA2560[17]) isn’t able to deal with a negative voltage.

The input signal has to be rectified. Using a full bridge rectified here is a bad idea because

the signal can be aliased due to the voltage drop across the diodes. Instead, a precision

full-wave rectifier[18] made of op amps can be used. The output signal is not distorted

but must stay between the positive power supply.

Here’s the circuit :

80 | 3.3 Hardware part of the digital implementation

Figure 3.9: Full-wave precision rectifier.

### 3.3.2 Comparator

The comparator plays a role in alerting the microcontroller when the voltage drops below

zero. It consists of an op amp supplied between positive voltage and ground. The op amp

works in unstable mode. It outputs a logical "1" only when the input voltage is below 0.

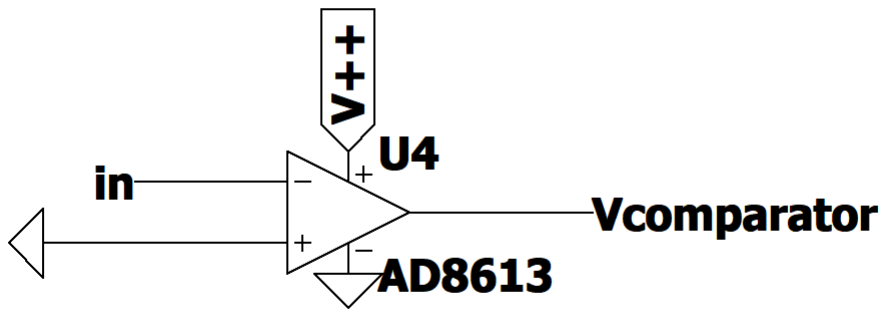
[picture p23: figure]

Figure 3.10: Comparator that outputs logical "1" if the input voltage is below the reference : 0 V.

### 3.3.3 Voltage follower

The microcontroller outputs a voltage vdac that has to be converted into current by the

voltage to current converter. It’s important to prevent the microcontroller from drawing

3.3 Hardware part of the digital implementation | 81

too much current. Thus a voltage follower is useful here. It’s characterised by its high

input impedance (Mega Ω).

Figure 3.11: Voltage follower.

### 3.3.4 Howland current source

The objective now is to convert the controlled voltage into current. This current will be

injected to the voltage generator in order to simulate a fictive inductive/capacitive load.

A famous circuit made of ap amps called Howland current source[19] allows

converting a voltage source to a current source into a load. This circuit plays the most

important role of the embedded circuit. It consists of an operational amplifier and a

balanced resistor bridge to maintain the constant current value through the load even if

the value of load resistance changes.

The idea is to keep the same principle of the Howland source by replacing the output

load by the generator :

82 | 3.3 Hardware part of the digital implementation

Figure 3.12: Howland current source. Vdac is the controlled voltage at the output of the DAC. It has to be converted into current. Vin_micro is the voltage of the generator which goes into the input pin of the microcontroller (before the voltage rectifier).

Assuming that the op amp is ideal and V

+=V

−, it can be deduced that :

V

− = Vo

R1
R1 + R2

= V

+ = VGENERAT OR

It can be deduced from the Ohm low that the current through R3 and R4 are :

IR3 =

Vdac − VGENERAT OR
R3

IR4 =

Vo − VGENERAT OR
R4

3.3 Hardware part of the digital implementation | 83

The current that goes through the generator can be computed using Kirchhoff’s current

law :

IGENERAT OR = IR3 + IR4 =

Vdac − VGENERAT OR
R3

+

Vo − VGENERAT OR
R4

=

Vdac − VGENERAT OR
R3

+

VGENERAT OR(R1 + R2)
R1R4

−

VGENERAT OR
R4

=

Vdac − VGENERAT OR
R3

+

VGENERAT ORR2
R1R4

=

Vdac
R3

+ VGENERAT OR(−

1
R3

+

R2
R1R4

)

If the following condition is satisfied :

1
R3

=

R2
R1R4

(xxv)

The current through the generator depends only on the voltage at the output of the DAC

becomes:

IGENERAT OR =

Vdac
R3

(xxvi)

Let’s now determine the values of the resistors R1, R2, R3, R4 such as the Howland and

the voltage follower op amp never saturates. The OPA548 is a good choice here because

it is internally buffered which allows 5 A peak. Furthermore, it can be supplied between

+/-30 V.

The output current of the Howland op amp is :

IOH = VGENERAT OR(

1
R4

+

1
R3
) ≤ 5 A | (xxvii)

And its output voltage :

VOH = VGENERAT OR(1 + R2
R1
) ≤ 25 V | (xxviii)

The output current of the voltage follower op amp is :

IR4 =

VDAC − VGENERAT OR
R3
≤ 5 A | (xxix)

84 | 3.3 Hardware part of the digital implementation

If the peak generator never exceeds 5 V, it can be derived from (xxvii) :

1
R4

+

1
R3
≤ 1 | (xxx)

In order to avoid any current saturation of the voltage follower op amp (xxvii) :

VDAC − VGENERAT OR ≤ 5R3

|VDAC − VGENERAT OR|max ≤ 5R3

R3 ≥ 1 | (xxxi)

From (xxviii), the following condition should always be satisfied to avoid a voltage

saturation :

R2
R4

≤ 4

Let’s choose R3 = 1 Ω in order to get a perfect mirror of the current at the output of the

DAC :

VDAC
1Ω = IGENERAT OR

But this is a bad idea since the condition (xxviii) will never be satisfied. This may lead

to a current saturation of the Howland op amp.

Let’s take instead R3 = 2Ω and R4 = 2Ω. The condition (xxx) is thus satisfied.

In order to always satisfy the condition (xxv) :

R2 = R3 = 10kΩ | (xxxii)

The resistor R3 plays the role of a conversion gain between voltage and current. if It is

chosen equal to 2 Ω, there will always be a factor 2 between the VDAC and IGENERAT OR.

VDAC can be multiplied by 2 thanks to voltage amplifier and always get :

85

IGENERAT OR =

2VDAC
2

=

VDAC
1Ω

The input voltage VDAC is now a perfect image of the generator current IGENERAT OR.

### 3.3.5 Assembling digital and analog implementation

Figure 3.13: Final embedded digital implementation. See Appendix A for a landscape format of the digital implementation.

The output current that goes through the generator is a perfect image of the controlled

voltage v_dac. See LTspice file named : "DIGITAL RLC FILTER.asc". This circuit is

simulated for a 1 mF capacitor. The frequency of the input signal is Fsig = 100 Hz. The

sampling frequency Fs = 5000 Hz. The ADC is 10 bits accuracy and the DAC is 12 bits

accuracy.

# 4 Discussion

Two kinds of implementations have been suggested with their pros and cons. The analog

RLC impedance makes use of a gyrated capacitor and a gyrated inductor connected in

parallel with a potentiometer. The filtering process is performed analogically by contrast

86

to the digital RLC impedance. The main limitations for both implementations remain

the maximum output current and the maximum output voltage that can afford the op

amps. Those two parameters depends on the RMS value of the input voltage and its

frequency. They also affect the available range of inductance/capacitance values. This is

why the choice of a good op amp is important here. The op amps should be buffered in

order to allow a much larger output current. But the voltage saturation is unavoidable

at higher frequencies. The gyrators in the analog implementation and the Howland

current in the digital implementation make use of the negative feedback. Therefore the

gain bandwidth product of the op amp matters if we want to increase the 90-degree-

bandwidth for the analog impedance. The digital impedance allows switching easily

the configuration of the RLC impedance from parallel to series connection. Whereas

most gyrators are ground referenced, they can only replace an inductor/capacitor that is

returned to ground, but not a floating inuductor making impossible a series connection.

The maximum frequency of the input signal is limited by the sampling frequency of the

microcontroller (Shannon-Nyquist theorem).

The available inductance and capacitance range can be compared for both

implementations in the following table :

87

88

Let’s fix the input voltage and the input frequency bandwidth discussed with Mr N.

Martin (my internship supervisor) :

Ve ∈ [0, 5V ]

f ∈ [0 Hz, 1 kHz]

For the analog impedance, the resistors of the equivalent inductor/capacitor R1, R2, R3,

R4 and R5 have been computed in order to maximize the range of inductance/capacitance

values for the given range of input voltage and frequency.

Resitors | Gyrated inductor | Gyrated capacitor
R1 R2 R3 R4 R5 | variates 500Ω 500Ω 1000Ω variates, fixes L | 10 kΩ 10 kΩ 5 kΩ variates, fixes C 5 kΩ

Table 4.1: Values of resistors for the gyrated inductor/capacitor.

If the power op amp OPA548 is used for both implementations, the following available

capacitance/inductance range can be derived :

Available ranges

Elements simulated | Digital impedance | Analog Impedance
C L | [230 pF, 159 µF] [16 mH, 100 H] | [4 pF, 0.15 µF] [145 mH, 100 H]
Table 4.2: | Comparisons of available inductance/capacitance ranges between
analog/digital impedances.

As can be seen from the above table 4.2, the digital implementation offers more flexibility

to the range of the inductance/capacitance values. Furthermore, as shown in table

4.1, it containing fewer constraints than the analog impedance. Concerning the analog

implementation, the range of admissible capacitance/inductance values will strongly

89

depend on the values of the resistors around the op amp.

90

# 5 Conclusion

The goal of this thesis was to develop a programmable RLC impedance with adjustable

resistor, capacitor and inductor. Two kinds of implementations have been suggested.

First, the analog impedance whose inductance/capacitance values are adjusted using

potentiometers. Second, the digital implementation whose inductance/capacitance

values are fixed on software. Both implementations have their pros and cons.

The analog impedance is mainly limited by the maximum output voltage/current that

can afford the op amps of the gyrated capacitor and inductor. The theoretical limits

have been computed assuming an infinite open-loop gain with perfect negative feedback.

Several spice simulations have been performed to analyze the performance of the gyrators

using the precision op amp AD744. The gyrated capacitor and inductor have been

implemented on a breadboard using the LM324 op amp. The output current of the

generator has been compared with the simulated results on LTspice.

On the other hand, the main limitations of the digital implementation are the sampling

frequency and the maximum output current of the Howland current source op amp.

LTspice simulator has been used to assess the performance of the digital RLC filter for

different inductance/capacitance values.

Finally, the commonalities and differences of the two implementations are discussed in

the last chapter. The available inductance/capacitance ranges are compared for a fixed

input voltage and frequency bandwidth.

91

# 6 Appendix

## 6.1 Appendix A

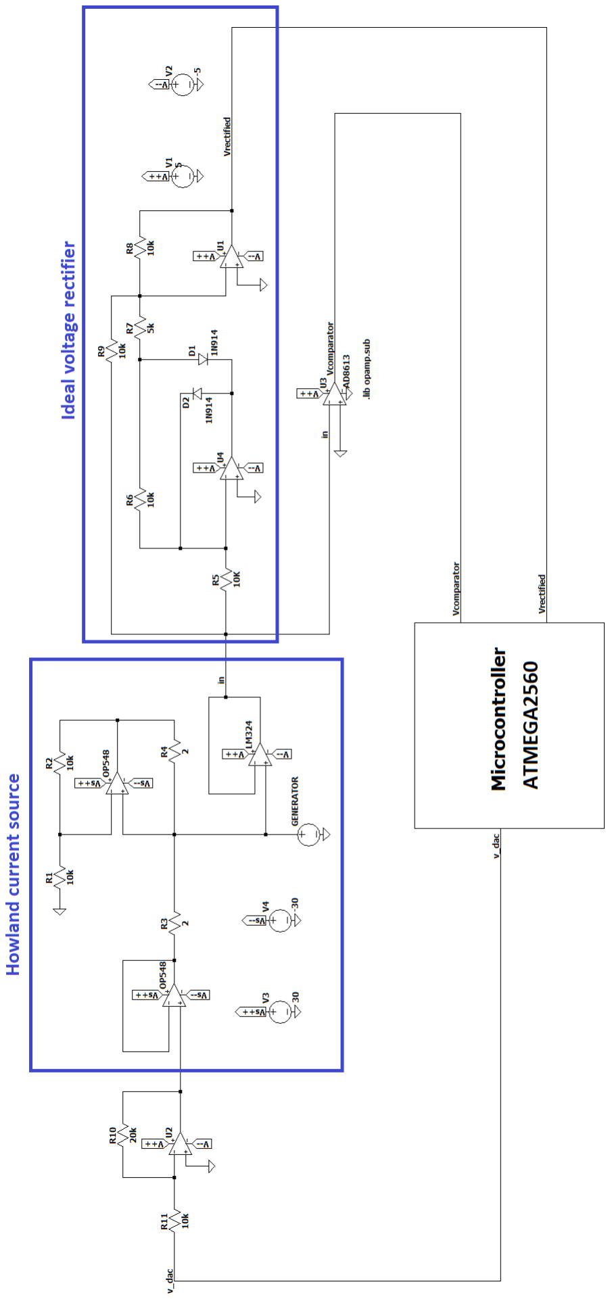
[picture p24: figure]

Figure 6.1: Final digital implementation of the programmable RLC impedance.

92 | 6.2 Appendix B

## 6.2 Appendix B

Figure 6.2: Final analog implementation of the programmable RLC impedance.

6.3 Appendix C | 93

## 6.3 Appendix C

### 6.3.1 The Space Center of Liège

The main objective of the Centre Spatial de Liège³ / Liège Space Center is to provide

products and services of the highest quality and to the satisfaction of all its partners.

The Centre Spatial de Liège (CSL) is determined to maintain the certifications relating to

its quality management system and to carry out its activities under controlled conditions

in accordance with its certifications, national and international standards in force.

The overall objectives of the CSL are defined as follows⁴
:
- Maintain a sustainable working environment;
- Satisfy the needs of its partners in technological innovation;
- Ensure the conformity of its products and services with applicable and contractually

defined standards and requirements (Cost - Quality - Timeliness and more

particularly in terms of "Design-to-Cost", "On-Time-Delivery", "OnQuality-

Delivery");

- Continuously improve internal operating procedures in terms of risk management,

skills management, reliability of project forecasts, protection of sensitive data, etc;

- Prepare for developments in the space industry in order to remain a key partner in

space instrumentation and in the spatial data processing value chain;

- Measure the performance of its processes and actions taken to improve the

effectiveness of its quality management system.

The CSL has many expertise :

1. Optics & Imaging : Design & Simulation, Calibration, Metrology, Remote

Sensing, ...

3This small appendix is taken from [20].

4
cited by Mr Michel BOGAERTS : Chief Executive Officier (ad interim).

94 | 6.3 Appendix C
2. Space Environment : Design Analysis, On ground Testing, Cleanliness and

Cyogenic application

3. COATING SURFACE TECHNOLOGIES : Thin films and coatings, Ion &

plasma processes, Micro nanostructures, Optical sensors, ...

4. THERMAL & MECHANICAL ENGINEERING : Thermal design &

Analysis, Mechanical design, Mechanism design, Cryogenics, Material & processes

5. ELECTRONIC ENGINEERING : Space verification facilities development,

Space scientific payloads development, Embedded systems engineering.

6. QUALITY : Quality & Risk Management, Product & Quality Assurance, National

Surveillance Organisation.

This master thesis is part from electronic engineering sector. The CSL has an electronic

lab⁵
that supports the design and development of any embedded system. The electronic

lab extensively supports the vacuum tests and the optical metrology by automating

the vacuum test facilities, robotizing the optical metrology benches and designing

and manufacturing stimulus Electrical Ground Support Equipment (EGSE) for optical

scientific payload.

The space center of Liège carries out electronics and software involving techniques such

as:

- Electrical cabinet design and manufacturing.
- Cable assembly design and manufacturing.
- PLC programming.
- Local and remote Human-Machine Interfaces (HMI) and Machine-to-Machine

(M2M) under Windows or Linux.

- Exotic protocols with the equipment or with the customers.
- Thermal regulation.
- Data acquisition, logging, analysis and reporting.
- Actuation of mechanisms and valves.

5Nicolas Martin is the Head of Electronics lab.

6.3 Appendix C | 95
- Fine positioning and compensation of optical elements and lasers.
- Control of digital cameras.
- Analog front-end electronics design and manufacturing.
- Scripting.

CSL works in close collaboration with :

- AMPACIMON : develops innovative ń Dynamic Line Rating ż (DLR) systems

for transmission/distribution systems operators.

- FN HERSTAL : develops, manufactures and sells a complete range of state-

of-the-art, groundbreaking solutions developed around small caliber firearms and

associated ammunition.

- FZ : technology and innovation leader specialized in the field of 70mm air-to-ground

rocket systems (2.75 NATO Standard) in the defence market throughout the world.

- AMOS : delivers optical, mechanical and observation solutions using leading-edge

technologies, for astronomy, space, science and industry.

- DELTATEC : high-level design house specialised in advanced technologies.

Furthermore, the electronics lab offers extensive design, prototyping, system engineering

and project management services for the development of Instrument Control Units (ICU)

and Remote Terminal Controllers (RTC) for optical scientific payloads for Space.

As part of the ULiege, they benefit from close partnership with the scientific community,

particularly in the fields of:

- Observation of the Sun in the UV and EUV spectra
- Observation of the Earth in the visible spectrum
- X-ray detection
- Photometry

They also benefit from on-site environmental test facilities providing easy-access to

vacuum thermal cycling, vibration, shock and specific optical calibration and verification

equipment.

96 | References
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

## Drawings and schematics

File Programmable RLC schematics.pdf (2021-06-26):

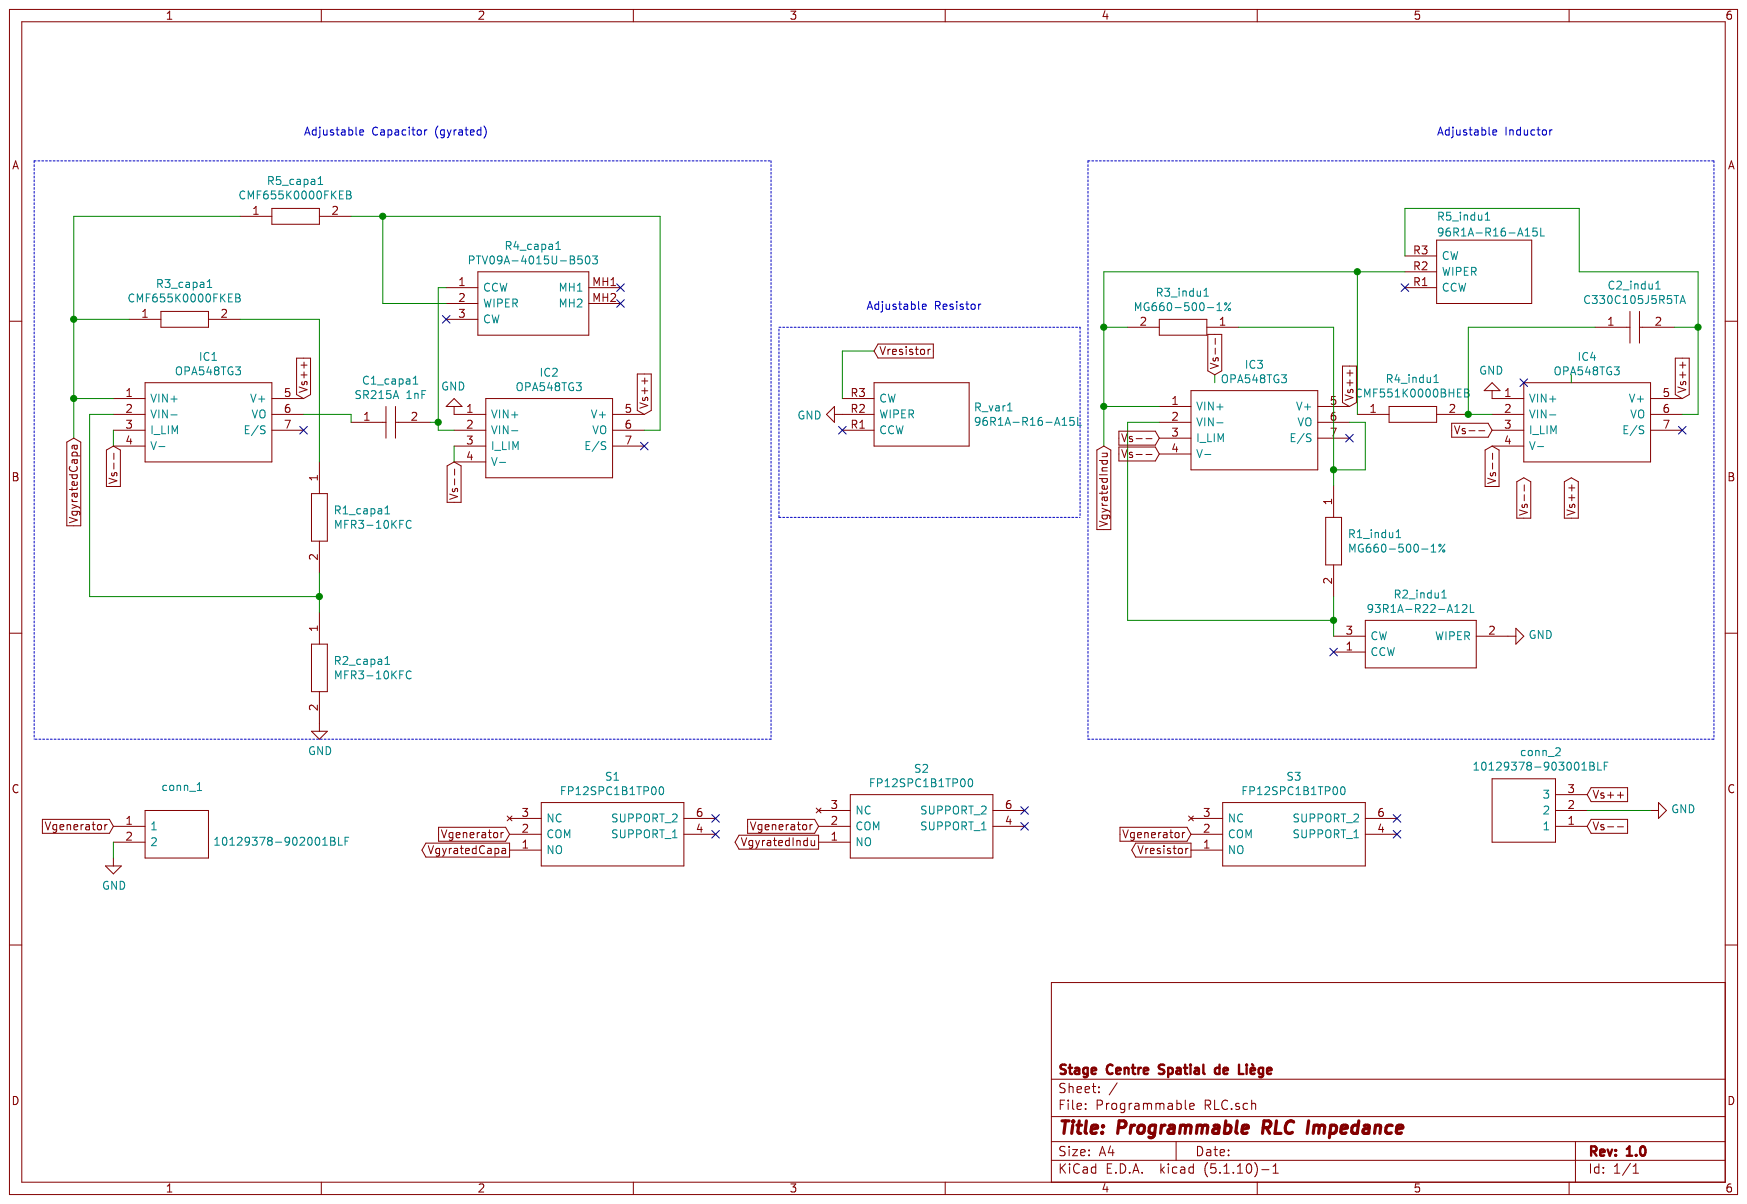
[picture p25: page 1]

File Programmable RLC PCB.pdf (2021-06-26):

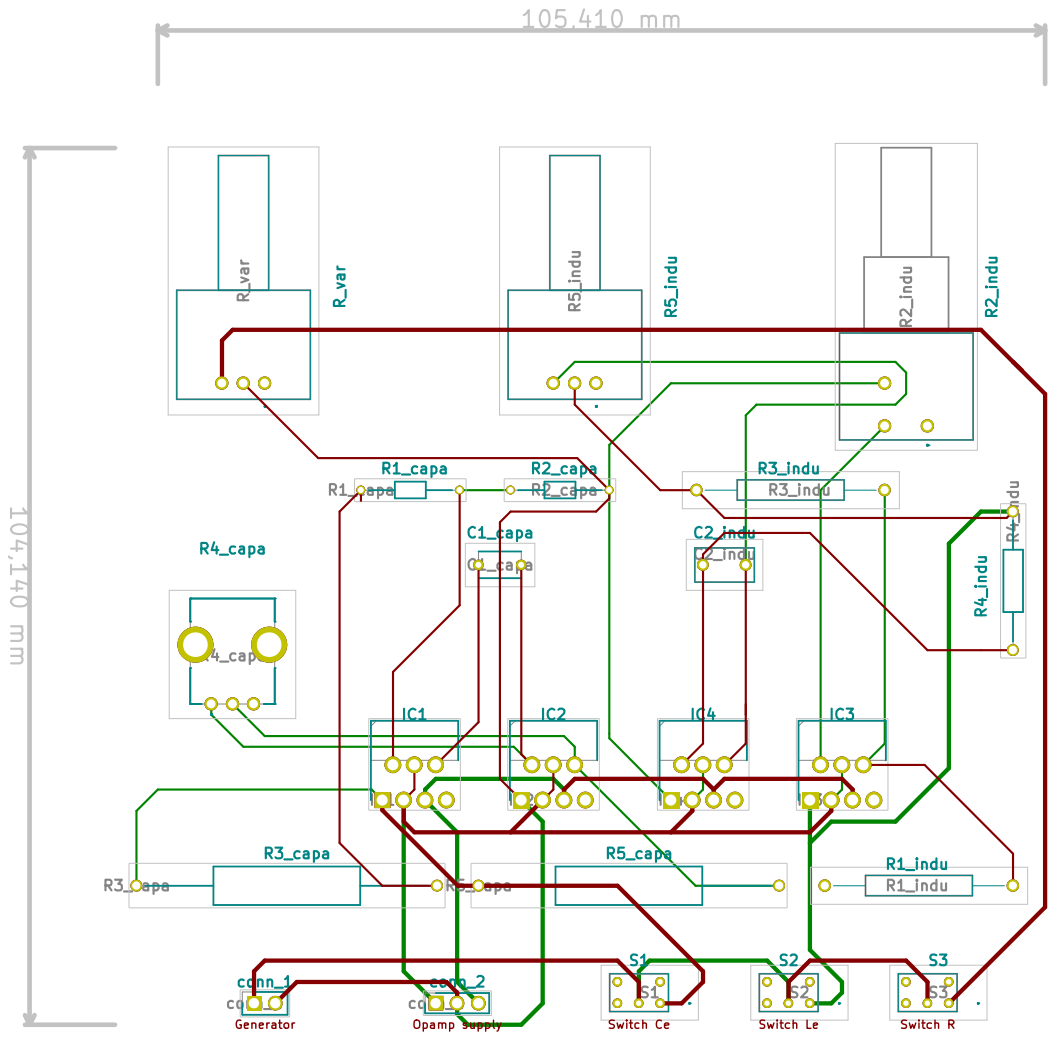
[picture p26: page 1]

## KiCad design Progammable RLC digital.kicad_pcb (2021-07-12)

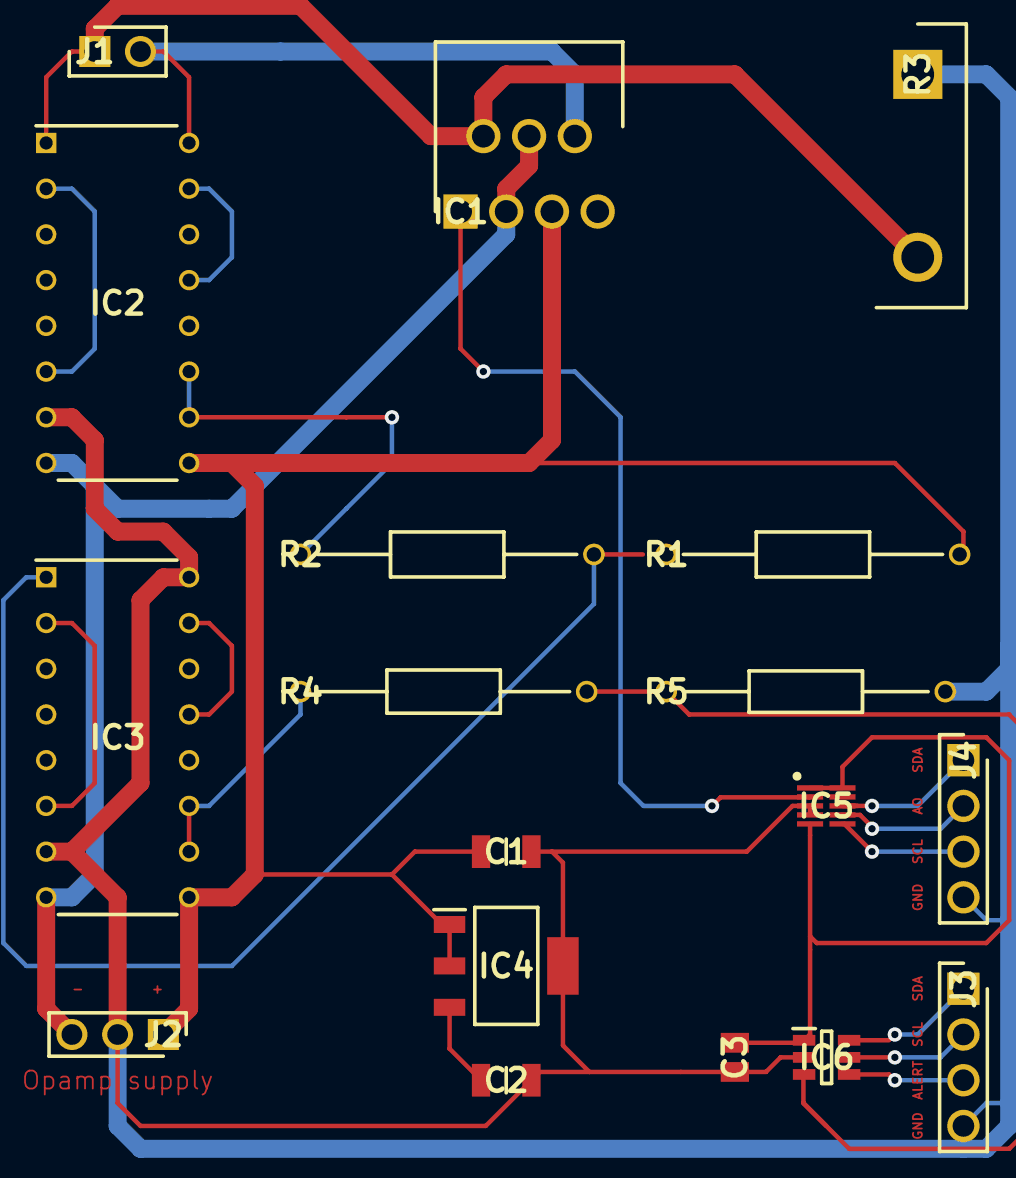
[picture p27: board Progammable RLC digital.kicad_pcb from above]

Board: 2 copper layers, 18 parts (0 on the bottom side), 22 nets.

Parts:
C1, C2: 12061C225KAT4A; CAPC3216X178N
C3: C0805X154K5RAC7800; CAPC2012X100N
IC1: OPA548TG3; TO127P470X1016X2195-7P
IC2, IC3: INA103KP; DIP794W53P254L1930H508Q16N
IC4: TPS7B8450QDCYRQ1; SOT230P700X180-4N
IC5: DAC60502DRXR; SON50P250X250X80-10N
IC6: ADC121C021CIMK_NOPB; SOT95P280X110-6N
J1: 10129378-902001BLF; HDRV2W67P0X254_1X2_508X241X843P
J2: 10129378-903001BLF; HDRV3W67P0X254_1X3_762X241X858P
J3, J4: G800W304018EU; HDRV4W69P0X254_1X4_1016X250X895P
R1, R2: MBB02070E5111BC100; RESAD1630W60L630D250
R3: LTO100F1R000FTE3; TO1016P500X1576X2420-2P
R4: MFR-25FTE52-30K; RESAD1590W60L630D240
R5: YR1B10KCC; RESAD1550W60L630D230

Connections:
ADC_ALERT: IC6.4, J3.3
ADC_SCL: IC6.5, J3.2
ADC_SDA: IC6.6, J3.1
DAC_A0: IC5.7, J4.2
DAC_SCL: IC5.6, J4.3
DAC_SDA: IC5.8, J4.1
GND: C1.2, C2.2, C3.1, IC2.7, IC3.7, IC3.16, IC4.4, IC5.3, IC5.4, IC6.2, J2.2, J3.4, J4.4, R3.1, R5.2
unnamed: IC2.2, IC2.6
unnamed: IC2.13, IC2.15
unnamed: IC3.1, R1.1, R2.2
unnamed: IC3.2, IC3.6
unnamed: IC3.10, IC3.11, R4.1
unnamed: IC3.13, IC3.15
V_adc_dac: C3.2, IC5.1, IC5.5, IC5.10, IC6.1
Vadc_dac: C2.1, IC4.3
Vdiff: IC2.10, IC2.11, R2.1
Vfilter: IC1.1, IC5.2
Vgenerator+: IC1.2, IC2.1, J1.1, R3.2
Vgenerator-: IC1.6, IC2.16, J1.2
Vin_ADC: IC6.3, R4.2, R5.1
Vsupply+: C1.1, IC1.5, IC2.9, IC3.9, IC4.1, IC4.2, J2.1, R1.2
Vsupply-: IC1.3, IC1.4, IC2.8, IC3.8, J2.3

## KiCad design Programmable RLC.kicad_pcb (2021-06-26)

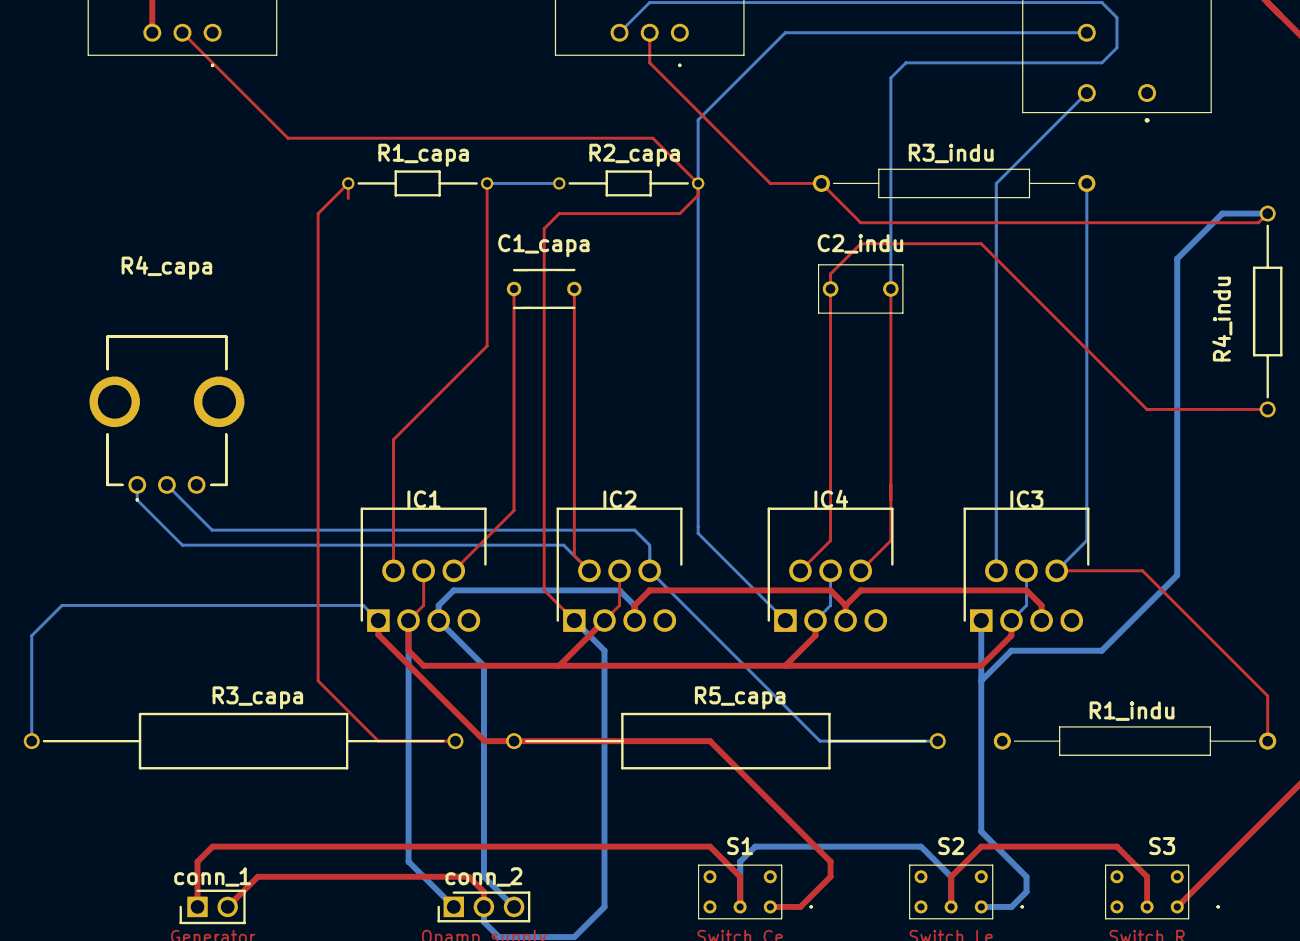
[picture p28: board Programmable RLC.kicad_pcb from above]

Board: 2 copper layers, 22 parts (0 on the bottom side), 16 nets.

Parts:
C1_capa: SR215A 1nF; SR215A102FARTR1
C2_indu: C330C105J5R5TA
IC1, IC2, IC3, IC4: OPA548TG3; TO127P470X1016X2195-7P
R1_capa, R2_capa: MFR3-10KFC; RESAD1170W45L370D200
R1_indu, R3_indu: MG660-500-1%; MG6605001
R2_indu: 93R1A-R22-A12L; 93R1AR22A12L
R3_capa, R5_capa: CMF655K0000FKEB; RESAD3573W69L1745D457
R4_capa: PTV09A-4015U-B503; PTV09A4015UB503
R4_indu: CMF551K0000BHEB; RESAD1653W69L737D229
R5_indu: 96R1A-R16-A15L; 96R1AR16A15L
R_var: 96R1A-R16-A15L; 96R1AR16A15L
S1, S2, S3: FP12SPC1B1TP00
conn_1: 10129378-902001BLF; HDRV2W67P0X254_1X2_508X241X843P
conn_2: 10129378-903001BLF; HDRV3W67P0X254_1X3_762X241X858P

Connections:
GND: IC2.1, IC4.1, R2_capa.2, R2_indu.2, R_var.R2, conn_1.2, conn_2.2
unnamed: C1_capa.1, IC1.6
unnamed: C1_capa.2, IC2.2, R4_capa.1
unnamed: C2_indu.1, IC4.2, R4_indu.2
unnamed: C2_indu.2, IC4.6, R5_indu.R3
unnamed: IC1.2, R1_capa.2, R2_capa.1
unnamed: IC2.6, R4_capa.2, R5_capa.2
unnamed: IC3.2, R1_indu.2, R2_indu.3
unnamed: IC3.6, R1_indu.1, R3_indu.1
unnamed: R1_capa.1, R3_capa.2
Vgenerator: S1.2, S2.2, S3.2, conn_1.1
VgyratedCapa: IC1.1, R3_capa.1, R5_capa.1, S1.1
VgyratedIndu: IC3.1, R3_indu.2, R4_indu.1, R5_indu.R2, S2.1
Vresistor: R_var.R3, S3.1
Vs++: IC1.5, IC2.5, IC3.5, IC4.5, conn_2.3
Vs--: IC1.3, IC1.4, IC2.3, IC2.4, IC3.3, IC3.4, IC4.3, IC4.4, conn_2.1
